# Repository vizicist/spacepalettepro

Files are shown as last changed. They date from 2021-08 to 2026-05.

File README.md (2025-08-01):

<h1>Space Palette Pro</h1>
<p>
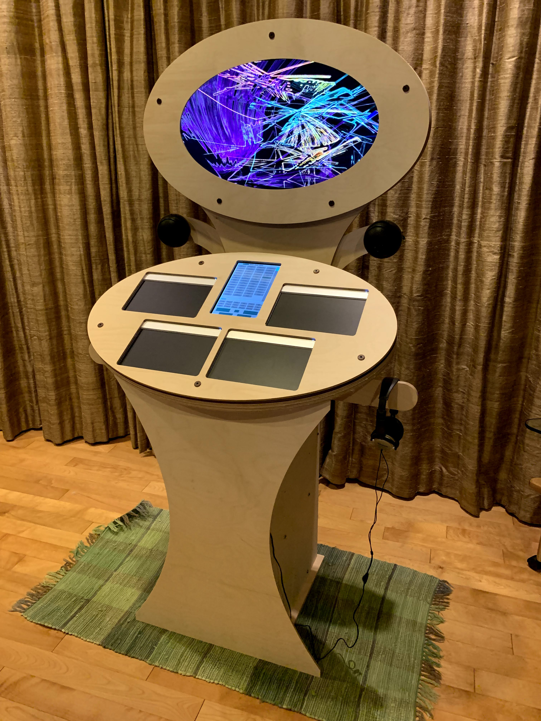
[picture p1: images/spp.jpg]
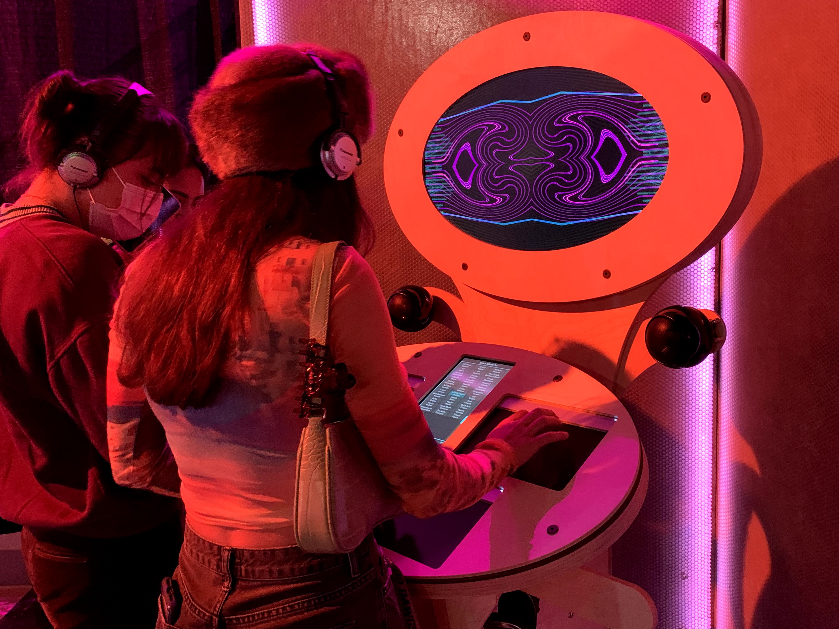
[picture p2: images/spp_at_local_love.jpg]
&nbsp;&nbsp;
<p>
NOTE: This repo is undergoing a massive rework for a more modular physical arrangement; the single monolithic
enclosure will be broken up into sections - one "core" section with all the electronics, and the other sections
will merely be support.  Besides being much easier to transport, it will also allow a desktop configuration.
The controller and monitor parts will be largely unchanged.
<p>
This repo contains open-source specs allowing you to completely reproduce the Space Palette Pro,
a visual music instrument on which you play music and graphics simultaneously by finger painting on
pressure sensitive pads.  Here are some <a href="https://photos.app.goo.gl/1x5BrCuc9yP6Z52XA">photos and videos</a> from a recent event where it was enjoyed.  Here is a <a href="https://youtu.be/HDtxEyCI_zc?t=362">improvised performance</a> using it.
<p>
Questions welcome, you can either submit an issue or email me@timthompson.com (aka <a href="https://nosuchtim.com">nosuchtim</a>)
<p>

<!--
<h2>Getting started with a single Morph as a visuals-only instrument</h2>
<p>
If you have Windows 10 and a Sensel Morph,
you can easily run the Palette software
as a visuals-only instrument with Resolume 7,
without building the complete Space Palette Pro.
It will even work with the demo version of Resolume Avenue or Arena.
Here are the instructions for
<a href="https://github.com/vizicist/palette/blob/main/doc/using_resolume.md">using a single Morph as a visuals-only instrument</a>.
-->

<h2>Building just the Space Palette Pro controller</h2>
<p>
Here are the instructions for <a href="doc/building_controller.md">building just the controller</a>,
which by itself would work well in many situations, for example doing performances.
In addition to 4 Morphs, you need the wood pieces, 2 USB hubs, the 10.1" touchscreen, and cables.

<!--
<h2>Building a complete and standalone Space Palette Pro</h2>
<p>
NOTE: If you plan on building a complete standalone Space Palette Pro, please send email to me@timthompson.com before starting,
since there have been major changes to the design of the base.
<p>
Here are the instructions for <a href="doc/building.md">building a complete and standalone Space Palette Pro</a> from scratch.
The cost of all the <a href="doc/parts.pdf">raw materials</a> for an uncompromised and complete instrument
including the computer is around $8K.
This is no-compromise single-item pricing of all materials - cost-reductions
and other adjustments are certainly possible.
For example, the speaker system is unnecessary
if you already have an amplifier and speakers.
Four sets of headphones and a headphone amp may not be needed either.
You might have access to a large CNC machine so you can avoid
paying someone else to CNC all the wood.
<p>
-->

<h1>Documentation</h1>
<a href="doc/README.md">Other documentation and important links can be found here.</a>
<p>
<p>
Any questions, email <a href="mailto:me@timthompson.com">me@timthompson.com</a>

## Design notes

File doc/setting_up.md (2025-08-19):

<h1>Setting up the Space Palette Pro</h1>
You should have these 5 pieces:
<br>1 - core box with all the electronics
<br>2 - oval controller with 4 Morphs
<br>3 - oval monitor
<br>4 - base boxes
<br>5 - plastic bin with misc. parts
<hr>
Here's the core box. Unscrew the thumbscrew, remove the protective panel, and screw the thumbscrew back into the core box.
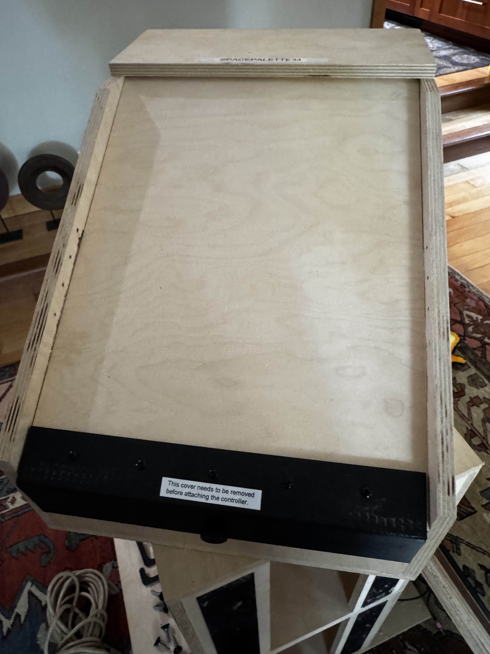
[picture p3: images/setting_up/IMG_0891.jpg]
<br>
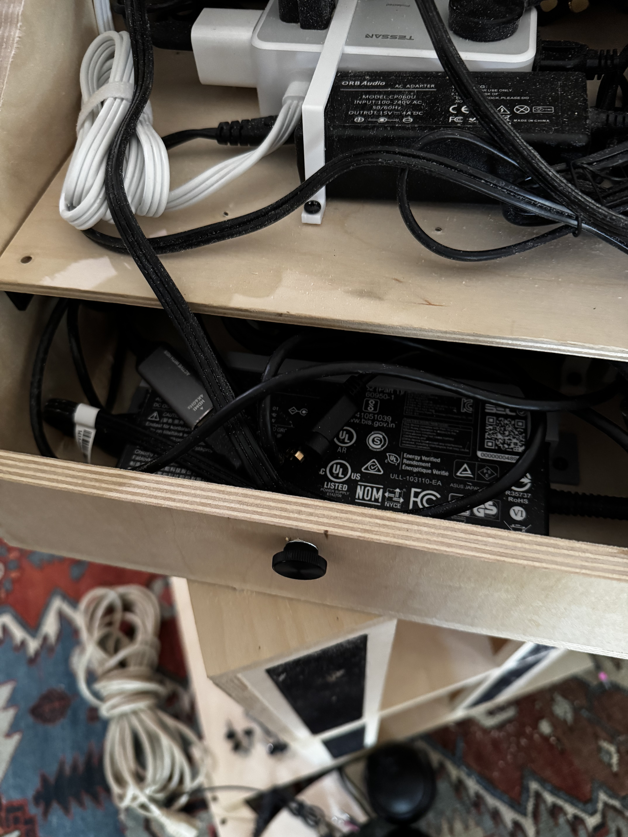
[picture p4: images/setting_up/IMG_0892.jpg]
&nbsp;
<hr>
The core box attaches to the base with 4 bolts (or thumbscrews) in the four corners of the box, which match up with four holes in the top of the base.
On the front side of the core box the holes are visible next to the power supply brick.
On the back side,
you'll need to unscrew the 2 thumbscrews on the back panel in order to fold the back panel down to get access to the two holes in the corners.
Getting these bolts in is the most finicky part of the setup, and small hands are an advantage.
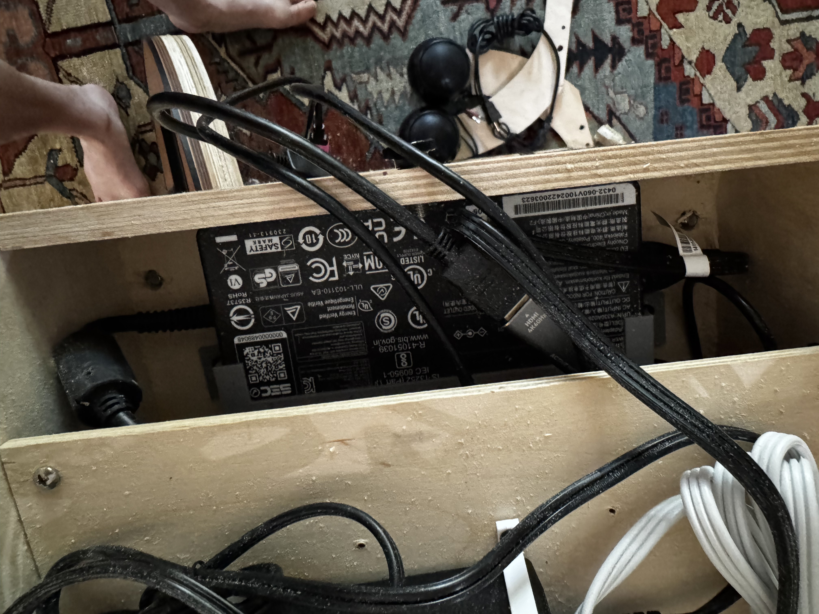
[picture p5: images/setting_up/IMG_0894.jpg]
<br>
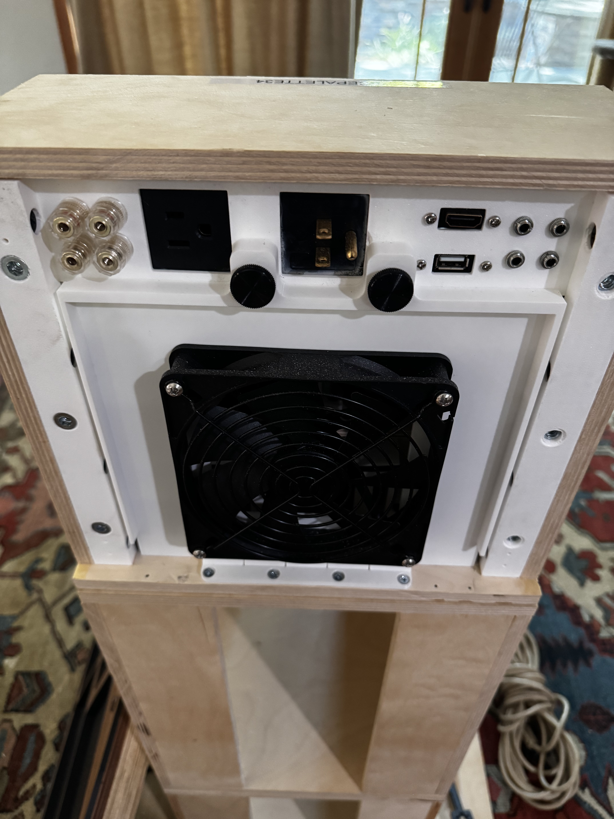
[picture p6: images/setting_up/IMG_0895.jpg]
&nbsp;
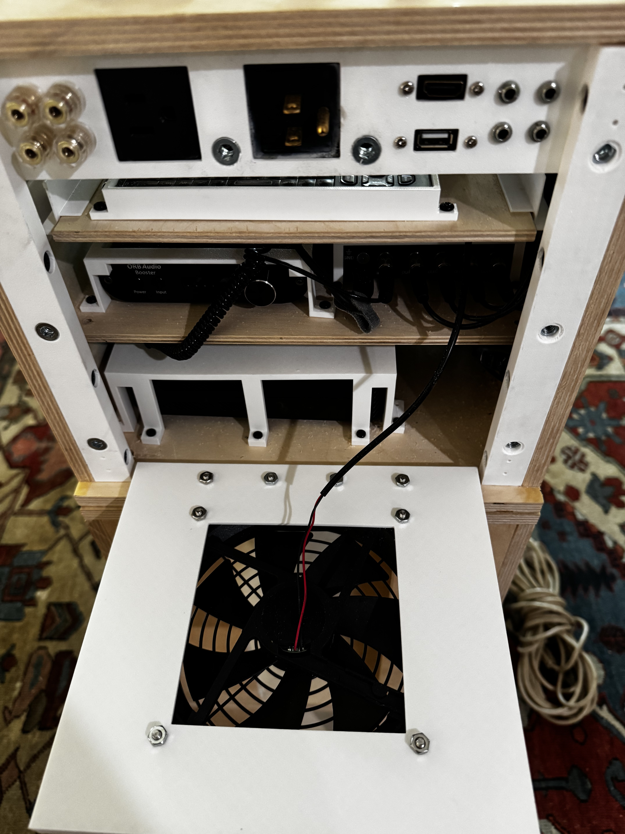
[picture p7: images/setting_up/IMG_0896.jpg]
&nbsp;
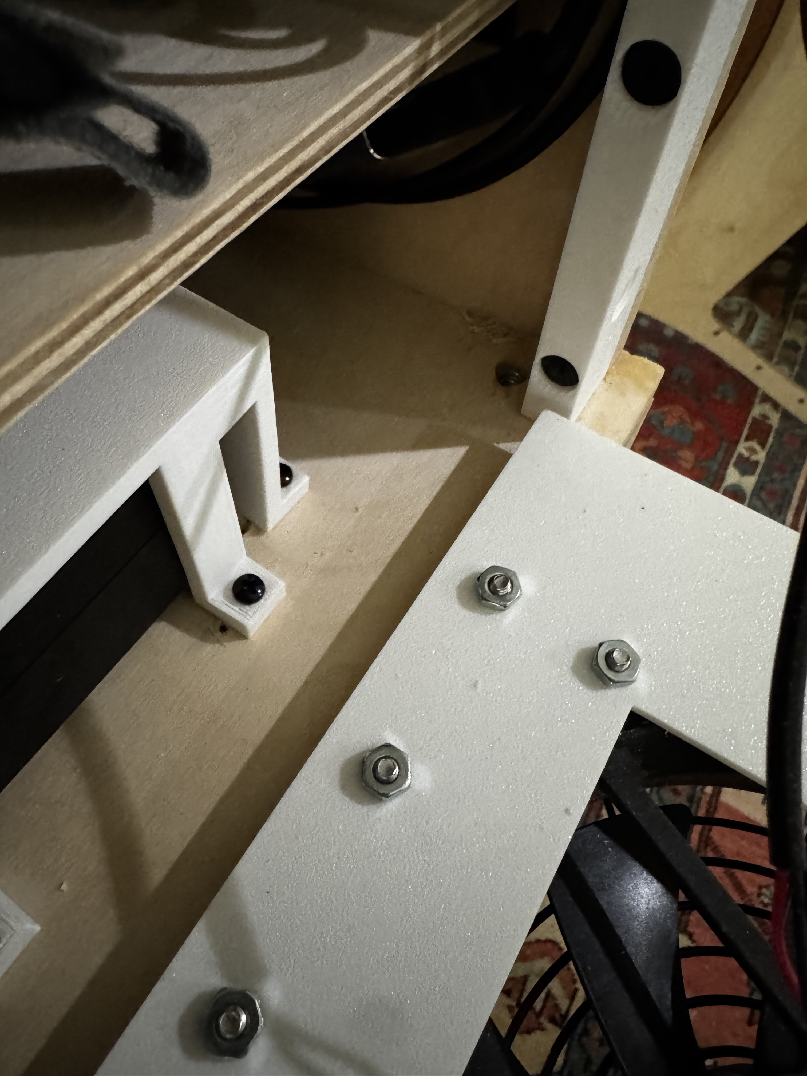
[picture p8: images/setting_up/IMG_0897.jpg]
&nbsp;
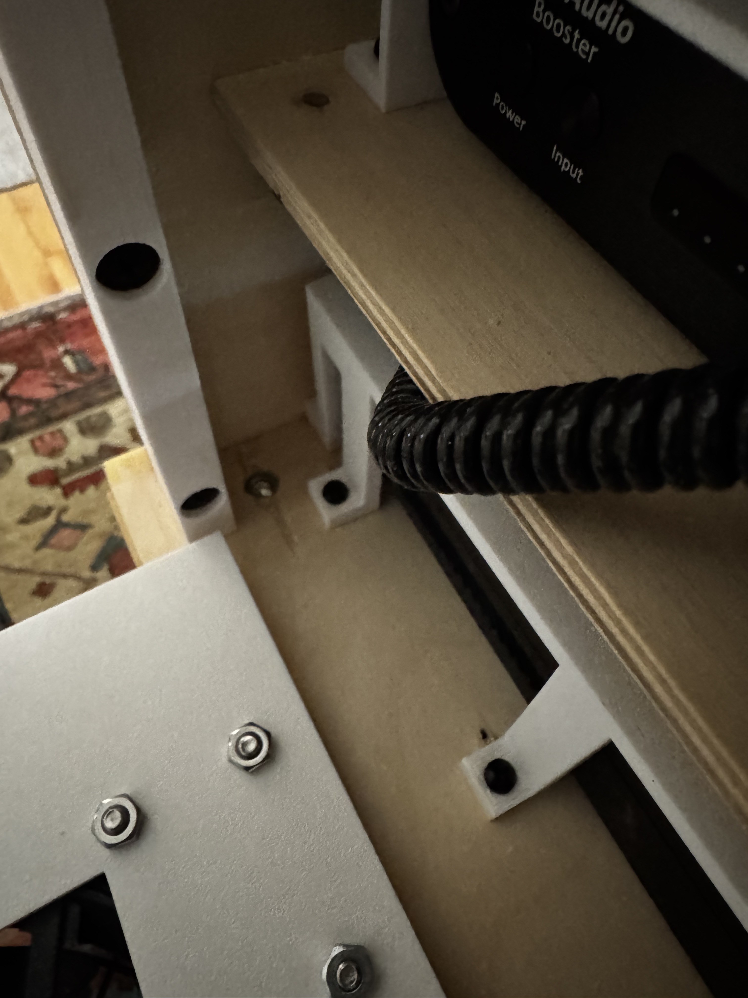
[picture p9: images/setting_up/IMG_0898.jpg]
&nbsp;
<hr>
Make sure you have these 2 cables (they are either in the plastic bin, or loose in the core box) before you attach the controller to the core box.  These are the 2 cables that will be connected to the monitor.
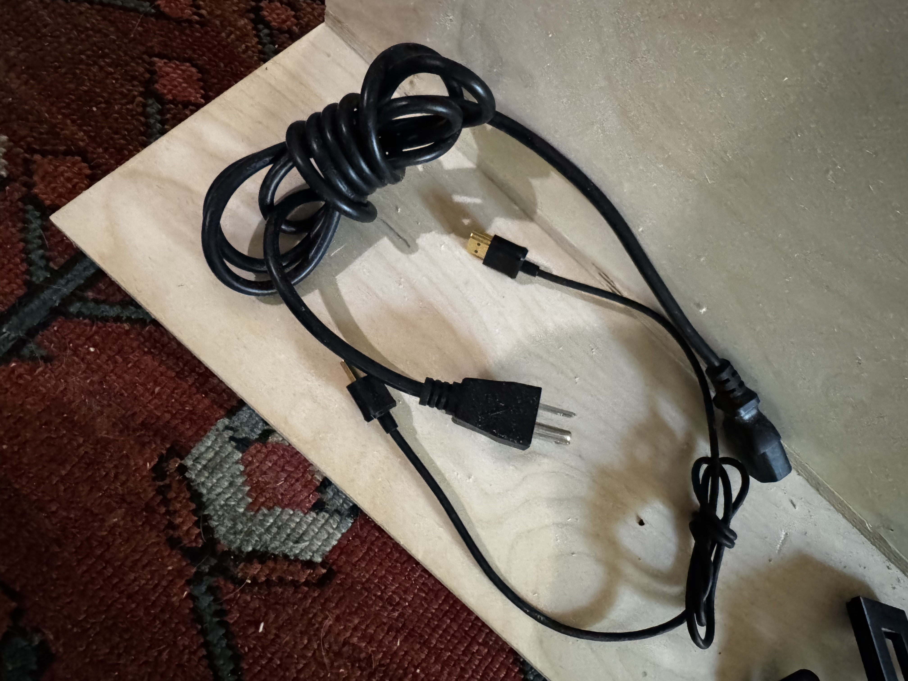
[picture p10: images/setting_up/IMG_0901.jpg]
<br>
<hr>
Identify the 3 cables (one HDMI, two USB C) in the core box that are going to connect to the oval controller.
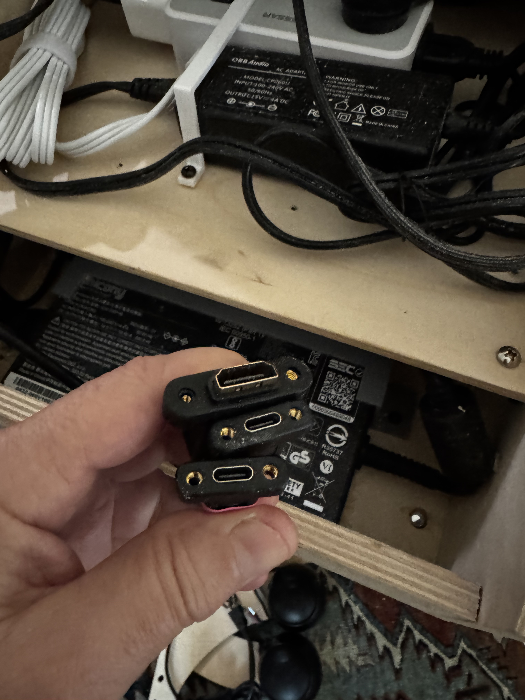
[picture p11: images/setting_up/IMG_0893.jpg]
<br>
<hr>
Position the oval controller close to the core so that you can connect the 3 cables from the controller to the core.  There are 2 USB C connections - one is colored pink, make sure that one is plugged into the corresponding pink connector.
<hr>
After connecting the 3 cables, place the oval controller on the core box, making sure that the 3 cables are tucked insude the core box, and use thumbscrews (2 on each side) to attach the oval controller to the core box.
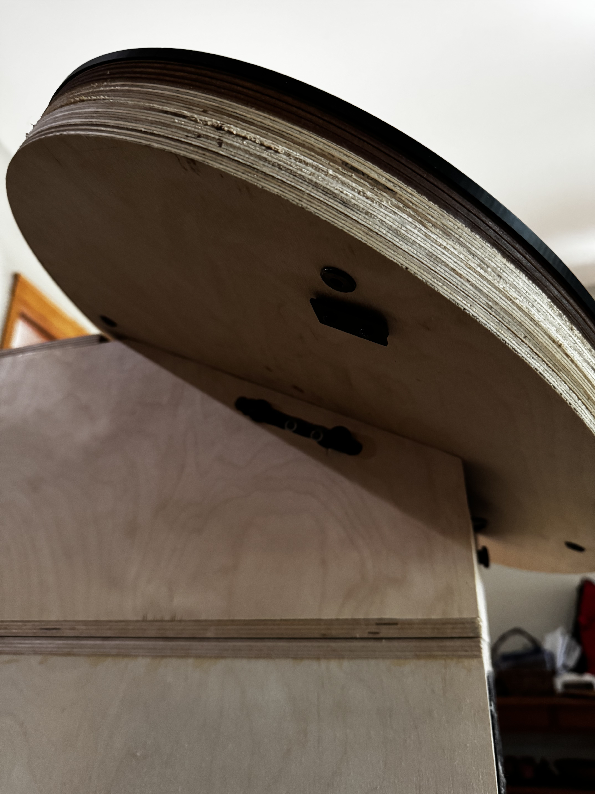
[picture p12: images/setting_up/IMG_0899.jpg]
<br>
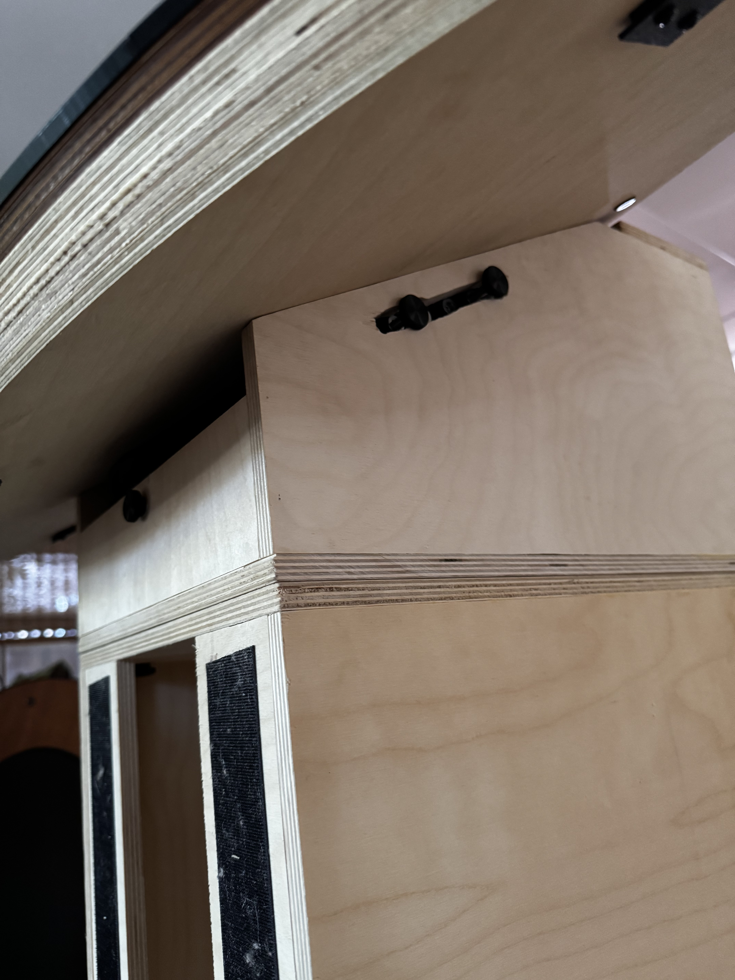
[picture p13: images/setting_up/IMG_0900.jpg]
&nbsp;
<hr>
Attach the monitor to the back of the core box with 6 thumbscrews.
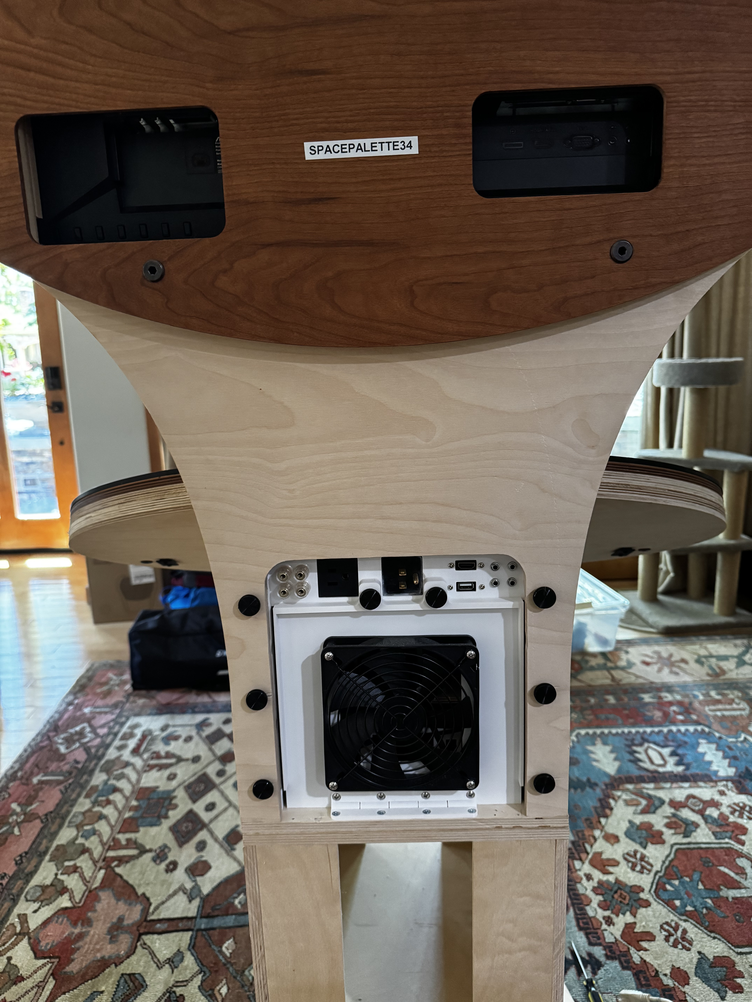
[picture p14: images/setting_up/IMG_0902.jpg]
<br>
<hr>
Connect the monitor to the back panel of the core box with 2 cables, one HDMI and one IEC/power.
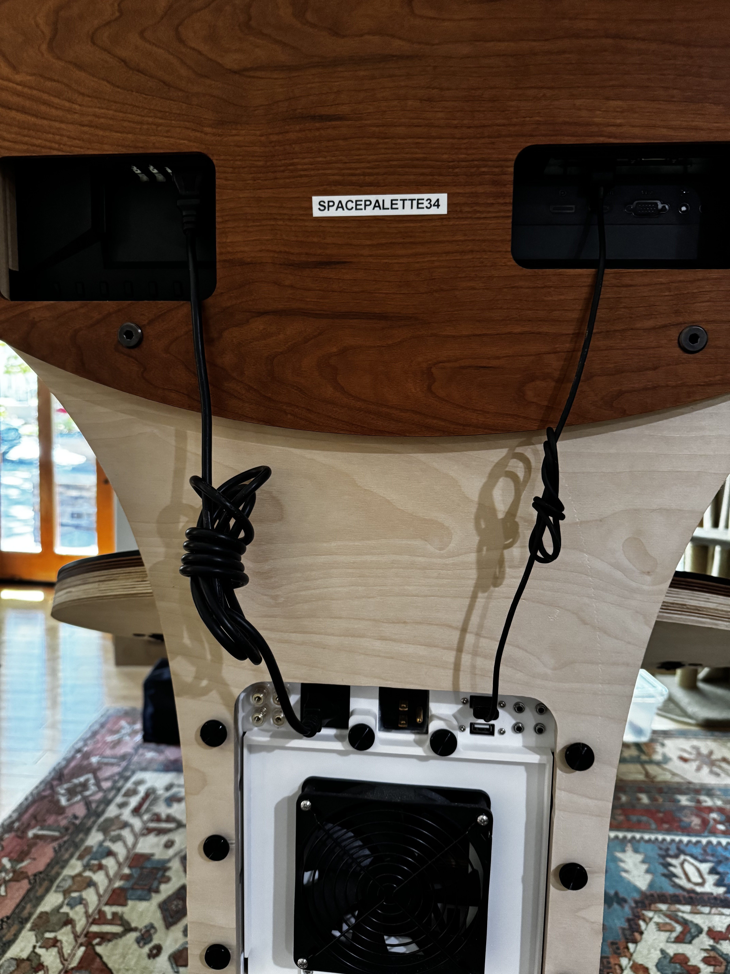
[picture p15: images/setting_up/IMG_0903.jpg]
<br>
<hr>
Slide the headphone hooks onto the matching plastic thing on the back side of the oval controller.
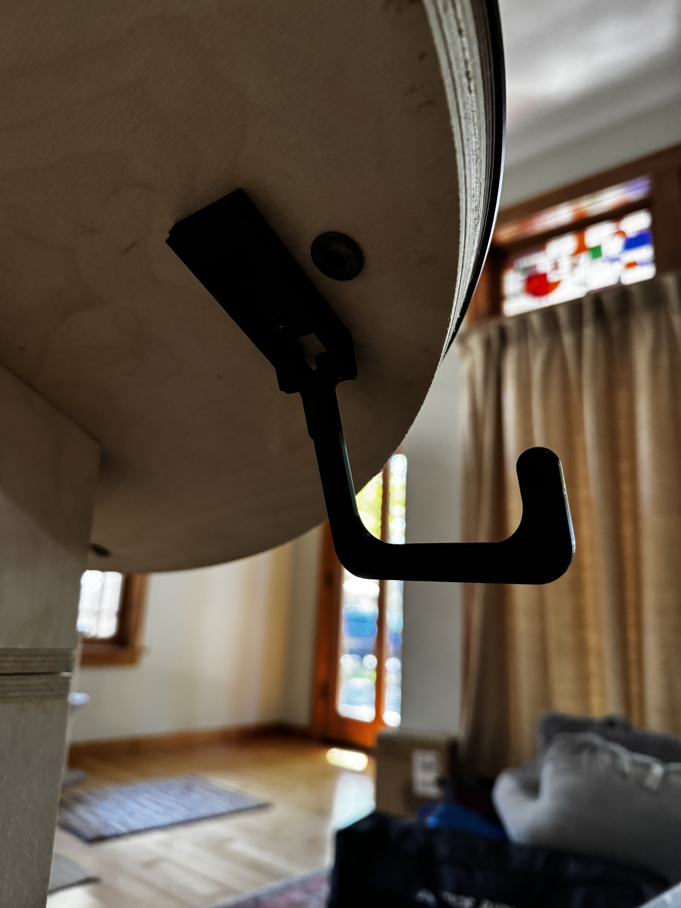
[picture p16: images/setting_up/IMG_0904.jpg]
<br>
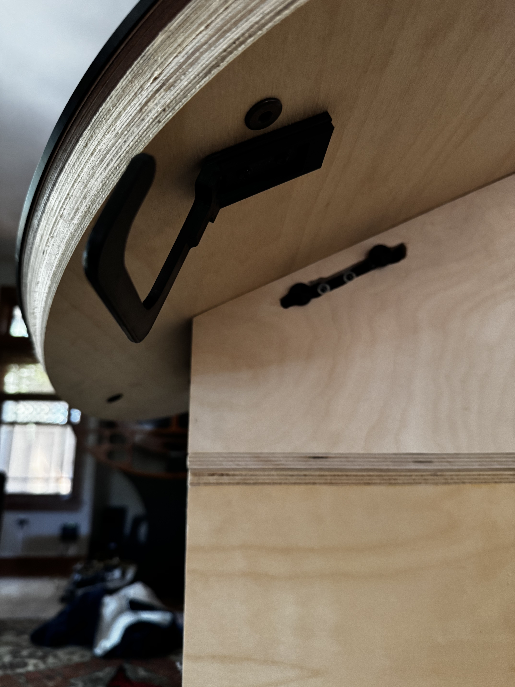
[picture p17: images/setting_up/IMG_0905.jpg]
&nbsp;
<hr>
Attach the speakers to the back, using (unscrewing/screwing) the thumbscrews that you've already used for the monitor.
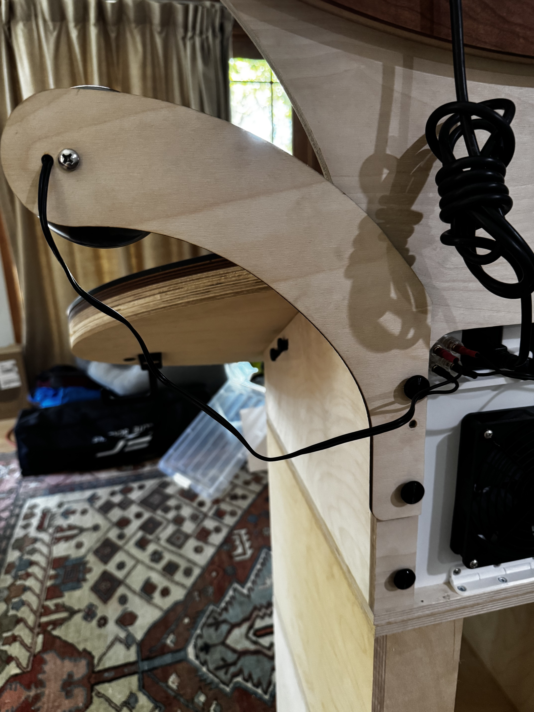
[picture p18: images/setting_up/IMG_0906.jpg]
<br>
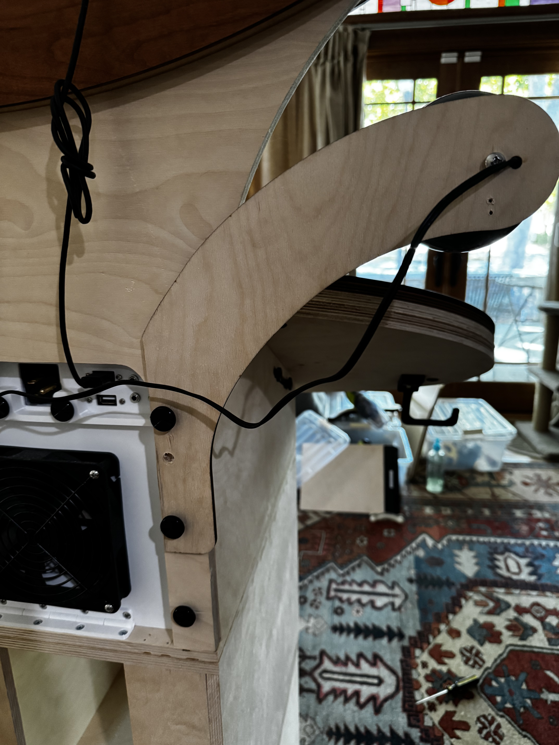
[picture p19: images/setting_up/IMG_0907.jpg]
&nbsp;
<hr>
Plug the banana plugs of the speakers into the jacks on the back panel.
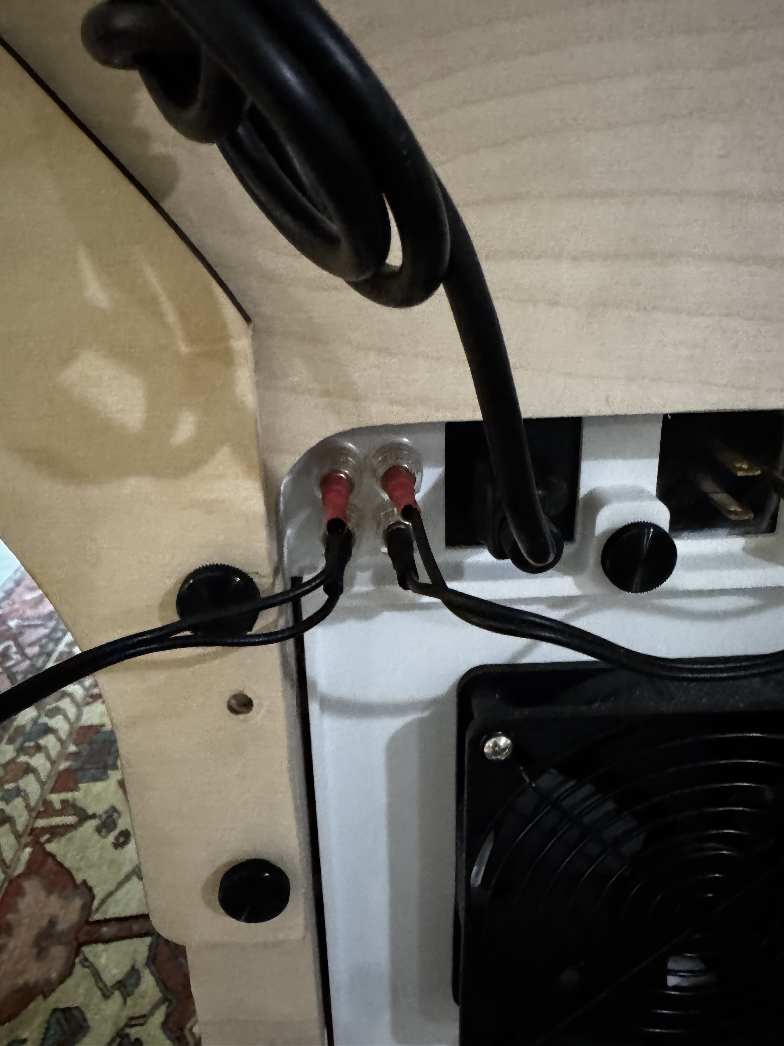
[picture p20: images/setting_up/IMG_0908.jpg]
<br>
<hr>
Plug the headphones into the jacks on the back panel.
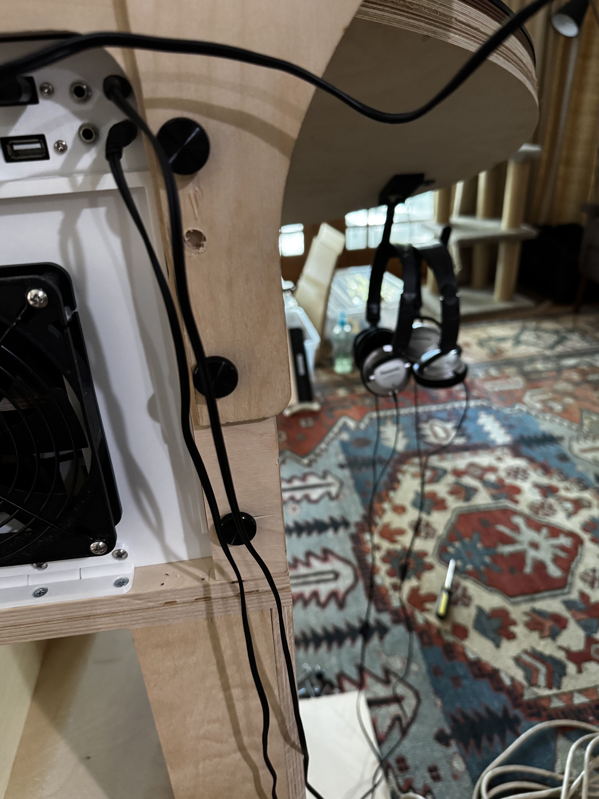
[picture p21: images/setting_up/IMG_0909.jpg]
<br>
<hr>
Plug the female end of a power cord into the male power connection on the back panel.  You may need to use a short extension cable.
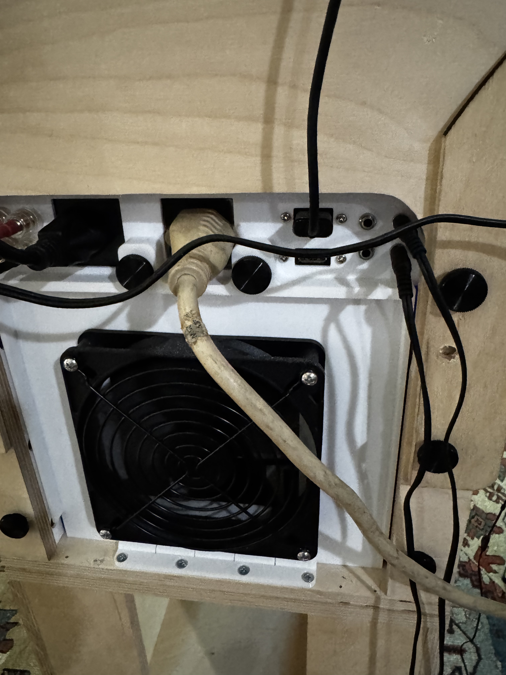
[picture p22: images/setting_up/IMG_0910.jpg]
<br>
<hr>
It should boot up in a few minutes after connecting the power.
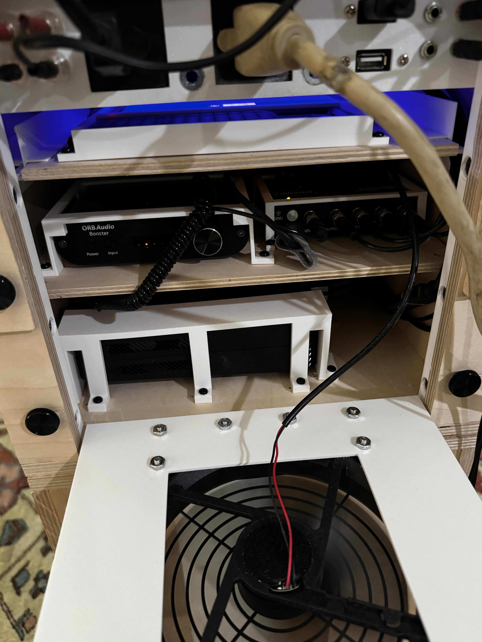
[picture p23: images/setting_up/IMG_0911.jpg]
<br>
<hr>
Normally, you shouldn't need to do anything else, but if there is a problem, you can check on things by sliding out the tiny keyboard and monitor after opening the back panel.  The keyboard has a trackpad on the right side.  You may need to press the blue FN key on the lower left of the keyboard, to wake up the keyboard.  The trackpad should move the mouse, but the cursor may be on the other screens, so you'll have to move it around in order to see it.
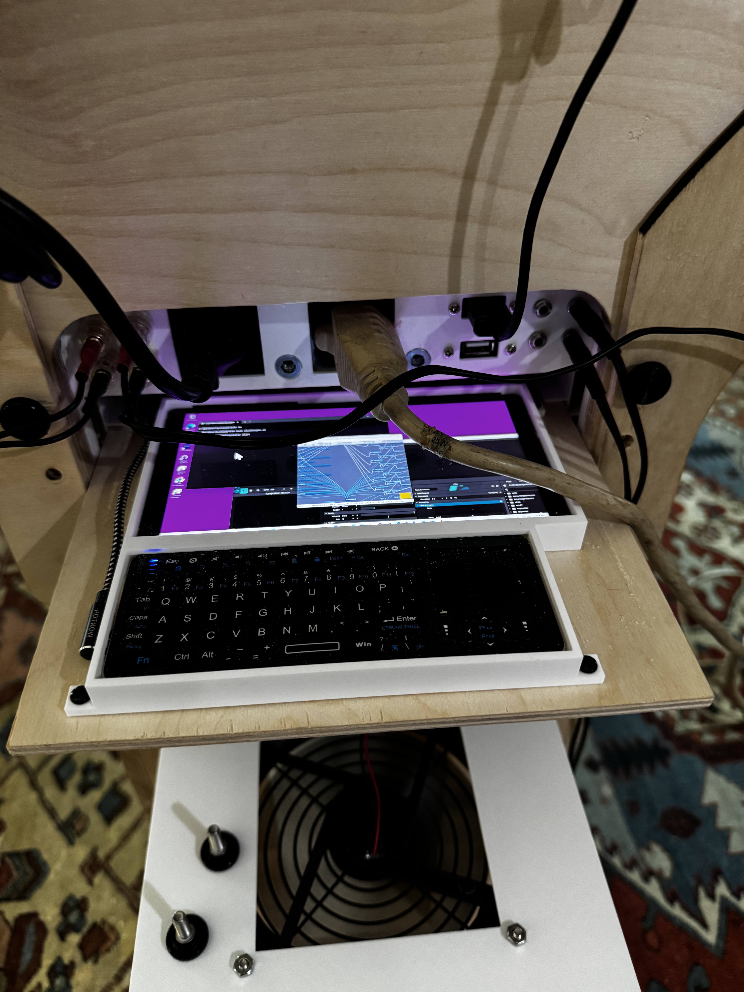
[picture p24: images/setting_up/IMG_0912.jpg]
<br>
<hr>
This is what the back looks like with everything connected.
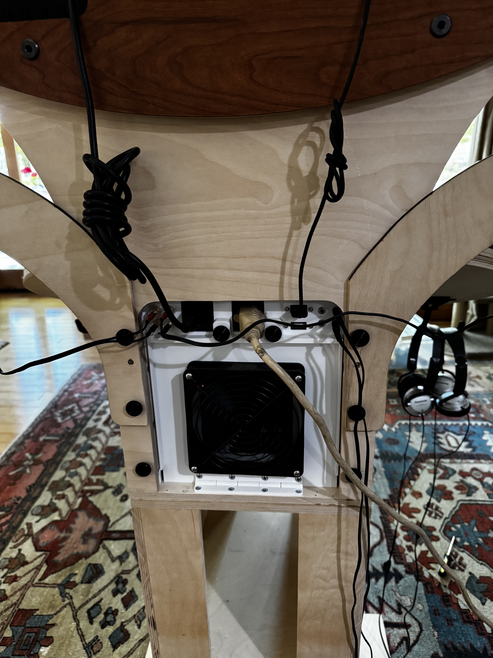
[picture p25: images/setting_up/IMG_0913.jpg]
<br>
<hr>
Put the hourglass panel on the front of the base, it attaches with velcro.
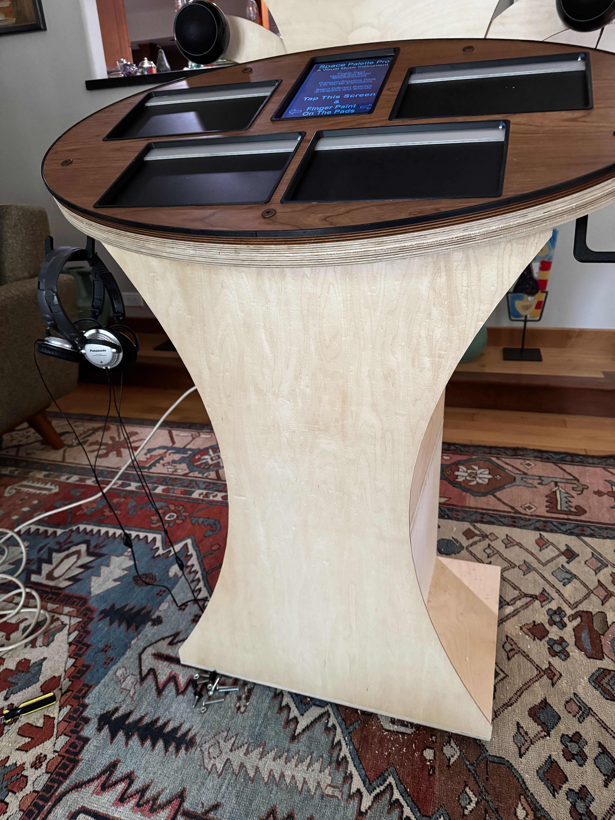
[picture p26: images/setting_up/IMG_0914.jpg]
<br>
<hr>
If you need to adjust the volume of the speakers, that is done with a single big knob on the speaker amp, accessible inside the back panel.  The headphones have volume controls on their cables for individual control.
<hr>
<h2>You now have a Space Palette Pro!</h2>

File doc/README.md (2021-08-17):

<h1>Space Palette Pro - documentation & other links</h1>
<p>
<li>
<a href="parts.pdf">Complete parts list with links and prices</a><br>
This is for the exact parts, down to the bolts,
needed to duplicate an uncompromised and complete instrument.
If you're viewing this file on GitHub,
the URL links for the parts won't be active
unless you download this .pdf and view it directly.
This parts list originates in a <a href="parts.ods">spreadsheet format</a>.
<p>
<li>
<a href="building.md">Full instructions for building it.</a>
<p>
<li>
<a href="../dxf/list.md">List of wood pieces with CNC data and pictures.</a>
<p>
<li>
<a href="computer_quote.pdf">Specs for the computer.</a>
<p>
<li>
<a href="https://github.com/vizicist/palette">Source code for the Palette software</a>
<p>
</ul>

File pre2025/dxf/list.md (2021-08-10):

<h1>DXF data for building a Space Palette Pro</h1>
<p>
Note carefully the quantity of each and the varying thicknesses.
<p>
<h1>Controller</h1>
<p>
<!-- NOTE: there must be a blank line before the table -->

| Quantity | Thickness | Filename | Image |
| --- | --- | --- | --- |
| 1 | 1/4" | <a href="SPP_Layer1_face.dxf">SPP_Layer1_face.dxf</a> |  |
| 1 | 1/8" | <a href="SPP_Layer2.dxf">SPP_Layer2.dxf</a> |  |
| 1 | 1/8" | <a href="SPP_Layer3.dxf">SPP_Layer3.dxf</a> |  |
| 1 | 1/8" | <a href="SPP_Layer4.dxf">SPP_Layer4.dxf</a> |  |
| 1 | 1/2" | <a href="SPP_Layer5.dxf">SPP_Layer5.dxf</a> |  |
| 1 | 1/2" | <a href="SPP_Layer6.dxf">SPP_Layer6.dxf</a> |  |
| 1 | 1/4" | <a href="SPP_Layer7_back.dxf">SPP_Layer7_back.dxf</a> |  |
<p>
<h1>Monitor</h1>
<p>
<!-- NOTE: there must be a blank line before the table -->

| Quantity | Thickness | Filename | Image |
| --- | --- | --- | --- |
| 1 | 1/4" | <a href="SPP_MonLayer1_face.dxf">SPP_MonLayer1_face.dxf</a> |  |
| 2 | 1/2" | <a href="SPP_MonLayer2_3_bottom.dxf">SPP_MonLayer2_3_bottom.dxf</a> |  |
| 4 | 1/2" | <a href="SPP_MonLayer2_3_leftright.dxf">SPP_MonLayer2_3_leftright.dxf</a> |  |
| 2 | 1/2" | <a href="SPP_MonLayer2_3_top.dxf">SPP_MonLayer2_3_top.dxf</a> |  |
| 1 | 1/2" | <a href="SPP_MonLayer4.dxf">SPP_MonLayer4.dxf</a> |  |
| 1 | 1/2" | <a href="SPP_MonLayer5.dxf">SPP_MonLayer5.dxf</a> |  |
| 1 | 1/4" | <a href="SPP_MonLayer6_back.dxf">SPP_MonLayer6_back.dxf</a> |  |
<p>
<h1>Base</h1>
<p>
<!-- NOTE: there must be a blank line before the table -->

| Quantity | Thickness | Filename | Image |
| --- | --- | --- | --- |
| 1 | 1/2" | <a href="SPP_BaseBack.dxf">SPP_BaseBack.dxf</a> |  |
| 1 | 1/2" | <a href="SPP_BaseBackBottom.dxf">SPP_BaseBackBottom.dxf</a> |  |
| 1 | 1/2" | <a href="SPP_BaseBottom.dxf">SPP_BaseBottom.dxf</a> |  |
| 1 | 1/4" | <a href="SPP_BaseFront.dxf">SPP_BaseFront.dxf</a> |  |
| 1 | 1/2" | <a href="SPP_BaseHeadphones.dxf">SPP_BaseHeadphones.dxf</a> |  |
| 1 | 1/2" | <a href="SPP_BaseKeyboard.dxf">SPP_BaseKeyboard.dxf</a> |  |
| 1 | 1/4" | <a href="SPP_BaseMidShelf.dxf">SPP_MidShelf.dxf</a> |  |
| 1 | 1/4" | <a href="SPP_BaseMonKeyShelf.dxf">SPP_MonKeyShelf.dxf</a> |  |
| 2 | 1/2" | <a href="SPP_BaseSide.dxf">SPP_BaseSide.dxf</a> |  |
| 2 | 1/4" | <a href="SPP_BaseSpeaker.dxf">SPP_BaseSpeaker.dxf</a> |  |
| 1 | 1/4" | <a href="SPP_BaseTopShelf.dxf">SPP_BaseTopShelf.dxf</a> |  |
<p>

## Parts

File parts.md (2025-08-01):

Space Palette Pro parts list

3d prints

	monkey holder
	monkey cable holder
	2x amp support
	headphone amp support
	4x angle4shelf (maybe rework to wide 2x)
	power brick support
	2x nuc support
	port panel
	2x ladder
	2x sliding side for monkey (make stronger)
	2x hinge for fan door
	2x speaker cable cover
	2x headphone hangers (A&B parts)

components

	Peakdo monitor
	Rii keyboard/mouse
	orb amp & power brick
	headphone amp
	power strip
	nuc 970 & power brick
	2x power cube
	usb fan

cables

	2x displayport to hdmi female
	mini hdmi to hdmi (for pico monitor)
	3-prong short male ac to 3-prong (to NUC power brick)
	3-prong short male ac to 3-prong female ac (to panel)
	usb Y-cable (Peakdo monitor or Rii keyboard package) usb c male to USB A female and male
	hdmi M/M short cable (from portpanel to big monitor)
	usb a female mount to usb a male
	hdmi female mount to hdmi male
	usb c (right angle) to usba (short)
	4x 1/8" stereo panel mount to male 1/8"
	1/8" stereo Y cable male to male/male (coiled)
	4x speaker cable (2 pairs black/red panel mounts to banana plugs)
	ac iec 3-prong short to big mon

wood box (one, need 2)

	2x   18 1/2" x 14"
	2x   18 1/2" x 12"
	4x   14" x 3"

wood bottom

	24" x 18 3/4"

wood core

	1/2" baltic birch (sides):
		18 1/2" x 12"
		12" x 5"
		2x   18 x 10" with diagonal 6 1/2" at top, 4 1/4" at side
		11 1/16" x 3"

	1/4" birch (shelves):
		14 x 11"
		8 x 8 7/8"

bolts and screws
    4 - 8-32 bolt - 1 3/8"  for attaching fan to panel
    4 - 8-32 bolt - 3/8" for attaching fan panel to hinge
    8 - 8-32 nuts
    4 - #6 x 1/2" flat head zinc philips for attaching hinge to base

    8 - threaded inserts 1/4-20 x 10mm 

    lots - #6 x 3/8" black wood screws for attaching to 1/8" shelves

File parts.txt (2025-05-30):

Space Palette Pro parts list

3d prints

	monkey holder
	monkeycable holder
	2x amp support
	headphone amp support
	4 × angleyshelf maybe legiel!
	powerr brick support
	2x nuc support
	port panel
	2x ladder
	2x sliding side for monkey (ms#kencer)
	2x hinge for fan poor
	-zis.ee#pkernear-keerkear& b)

components

	pico monitor
	pico keyboard
	orb amp & power brick
	headphone amp
	power strip
	nuc 970 & power brick
	2x power cube
	usb fan

cables

	2x displayport to hdmi female
	mini hdmi to hdmi (for pico monitor)
	3-prong short male ac to iec 3-prong (to NUC power brick)
	bp short male ac to 3p female ac (to panel)
	usb x-cable (pico mon orikey package) usb c to
	hdmi m-mi short to bigmon usba female immale
	usb a female mount to usb a male
	hdmi female mount to hdmi male
	usb c (right angle) to usba (short)
	4x 1/8" stereo panel mount to male 1/8"
	4x speaker cable
	ac iec 3-prong short to big mon

wood box (one, need 2)

	2x   18 1/2" x 14"
	2x   18 1/2" x 12"
	4x   14" x 3"

wood bottom

	24" x 18 3/4"

wood core

	8 1/4" x 8 15/16"  (with 5 1/4" hole)
	18 1/2" x 12"
	12" x 5"
	2x   18 x 10" (with diagonal 6 1/2" at top, 4 1/4" at side
	11 1/16" x 3"
	2x 10" x 1"

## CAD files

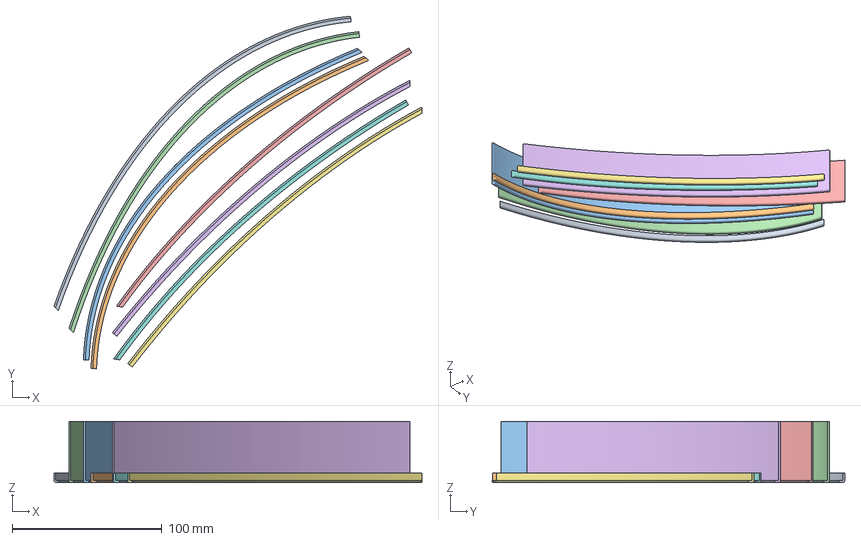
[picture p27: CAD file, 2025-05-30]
cad/SPP_Edge_AB_All.3mf
246.1 x 235.8 x 40.8 mm
SPP_Edge_B_0.25.stl
SPP_Edge_B_0.25_flipped.stl
SPP_Edge_B_1.5_flipped.stl
SPP_Edge_B_1.5.stl
SPP_Edge_A_1.5_flipped.stl
SPP_Edge_A_1.5.stl
SPP_Edge_A_0.25.stl
SPP_Edge_A_0.25_flipped.stl

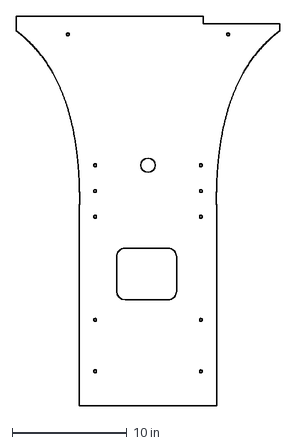
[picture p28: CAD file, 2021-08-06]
doc/cnc/PalPro_BaseBack.dxf
23.0 x 34.0 in

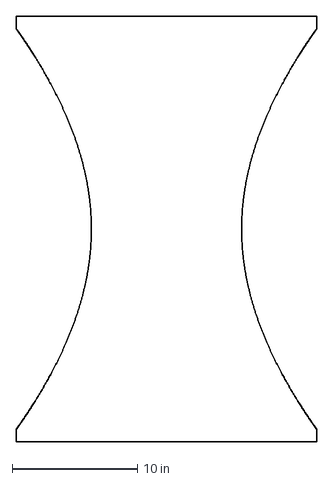
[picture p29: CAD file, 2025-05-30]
dxf/2025/basefront_noholes.dxf
24.0 x 34.0 in

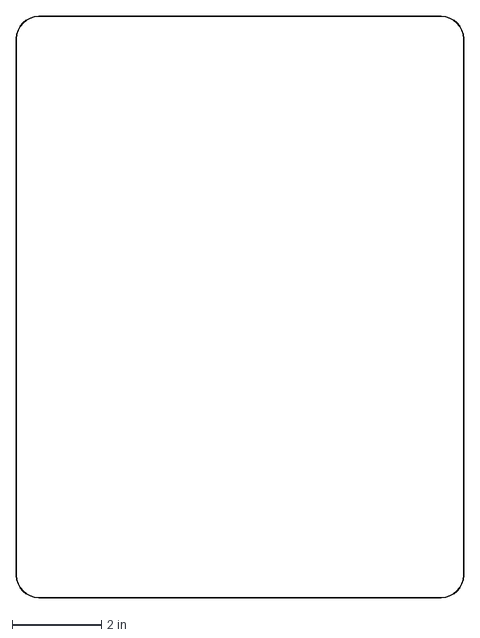
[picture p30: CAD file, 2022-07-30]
dxf/SPP_baseboxes_medium_outerinsert.dxf
10.0 x 13.0 in

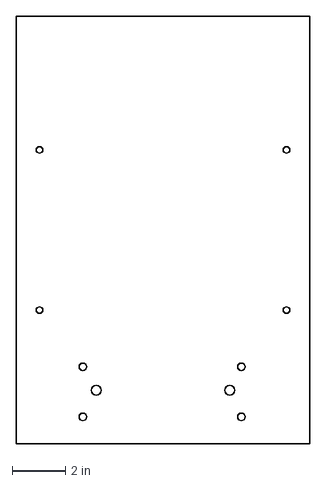
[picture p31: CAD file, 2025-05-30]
pre2025/dxf/SPP_BaseTopShelf.dxf
11.0 x 16.0 in

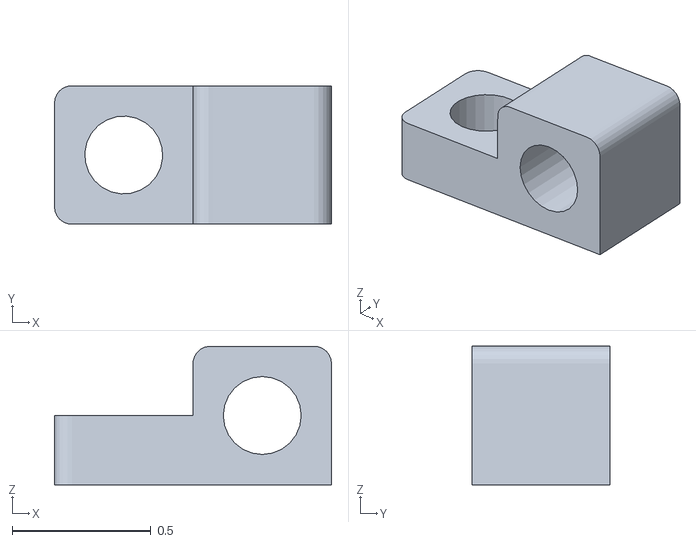
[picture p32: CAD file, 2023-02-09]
pre2025/stl/two_hole_bracket_sketchup.stl
1.00 x 0.5 x 0.5

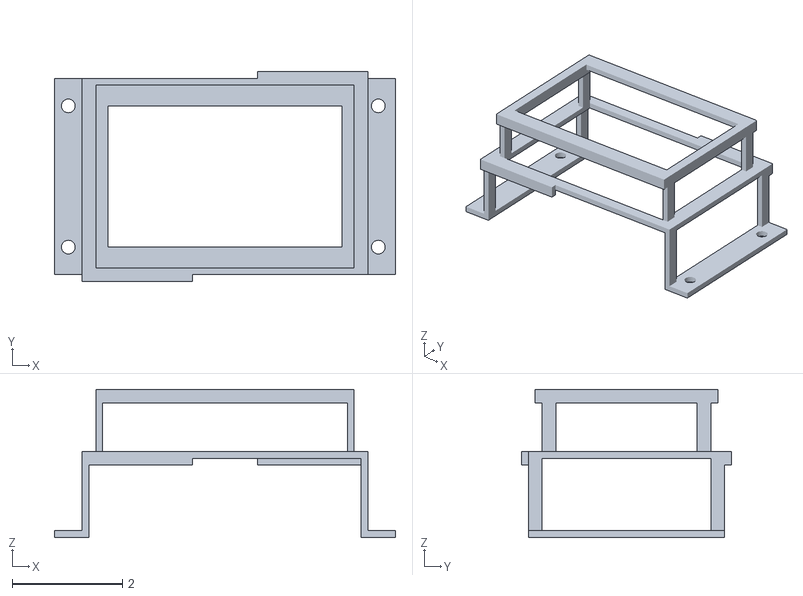
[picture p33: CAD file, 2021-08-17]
stl/amp_bracket.stl
6.19 x 3.81 x 2.69

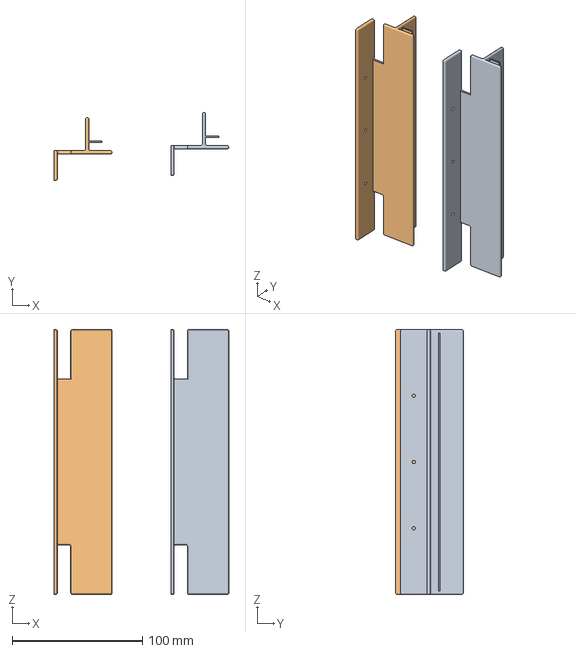
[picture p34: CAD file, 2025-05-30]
cad/SPP_sidesupport.3mf
133.9 x 52.1 x 203.2 mm
SPP_sidesupport.stl x 2

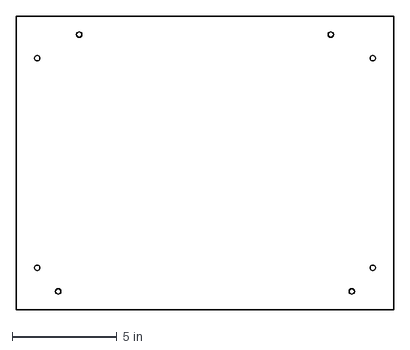
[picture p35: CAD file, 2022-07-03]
dxf/SPP_basebox_side.dxf
18.0 x 14.0 in

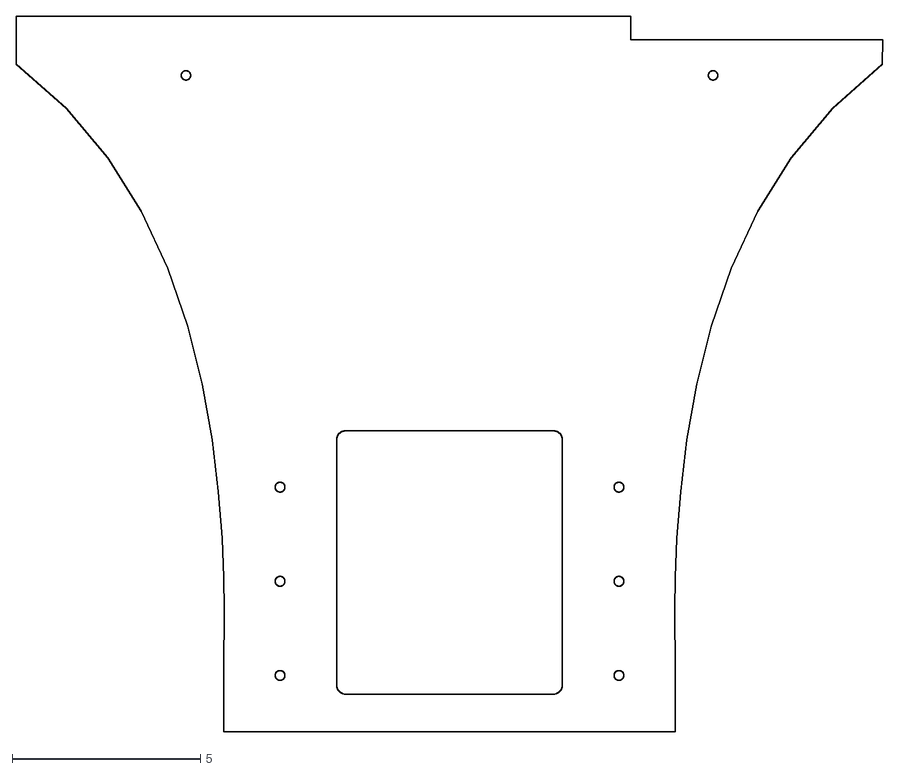
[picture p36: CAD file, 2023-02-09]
pre2025/dxf/SPP_BaseBack_skp.dxf
23.0 x 19.0

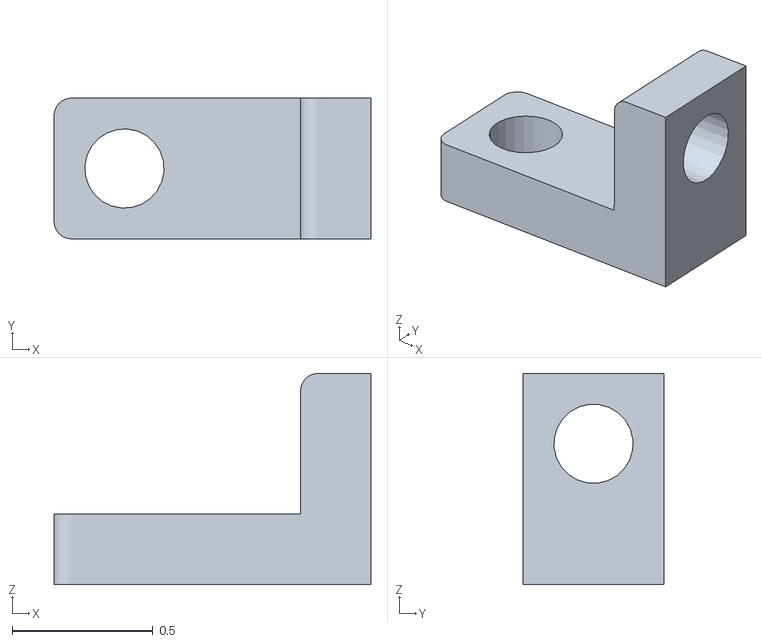
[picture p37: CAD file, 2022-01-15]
pre2025/stl/two_hole_front_bracket.stl
1.12 x 0.5 x 0.75

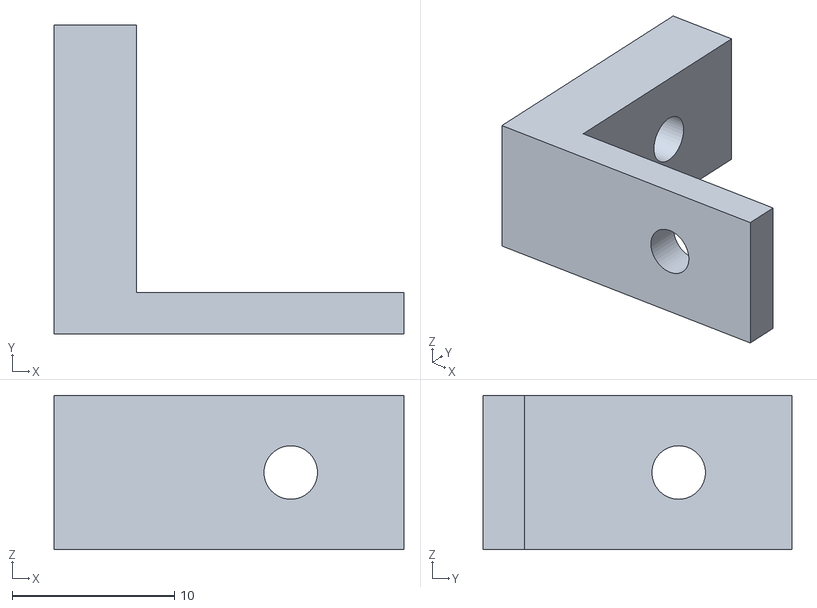
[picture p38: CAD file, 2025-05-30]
cad/SPP_angle4front.stl
21.6 x 19.0 x 9.53

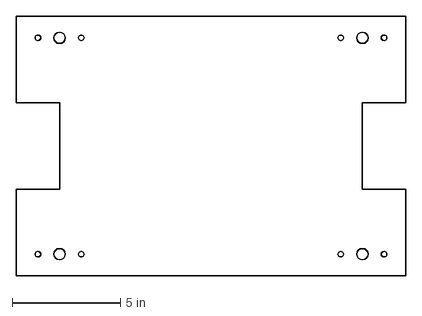
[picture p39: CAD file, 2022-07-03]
dxf/SPP_basebox_bottom.dxf
18.0 x 12.0 in

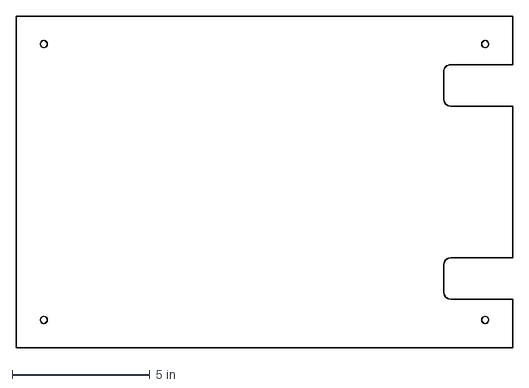
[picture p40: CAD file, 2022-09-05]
pre2025/dxf/SPP_baseboxes_top_bottom.dxf
18.0 x 12.0 in

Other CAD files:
pre2025/stl/two_hole_bracket.stl
cad/SPP_hinge.3mf
dxf/SPP_basebox_frontback.dxf
pre2025/dxf/SPP_baseboxes_medium_back_outer.dxf
cad/SPP_Edge_A_0.25.stl
cad/SPP_Edge_A_0.25_0.1.3mf
cad/SPP_Edge_A_0.25_flipped.3mf
cad/SPP_Edge_A_0.25_flipped.stl
cad/SPP_Edge_A_1.5.3mf
cad/SPP_Edge_A_1.5.stl
cad/SPP_Edge_A_1.5_flipped.3mf
cad/SPP_Edge_A_1.5_flipped.stl
cad/SPP_Edge_A_all.3mf
cad/SPP_Edge_All.3mf
cad/SPP_Edge_All_Old.3mf
cad/SPP_Edge_B_0.25.stl
cad/SPP_Edge_B_0.25_flipped.stl
cad/SPP_Edge_B_1.5.stl
cad/SPP_Edge_B_1.5_both.3mf
cad/SPP_Edge_B_1.5_flipped.stl
cad/SPP_Edge_B_all.3mf
cad/SPP_InnerEdge_A_0.25.stl
cad/SPP_InnerEdge_All.3mf
cad/SPP_InnerEdge_B_0.25.stl
cad/SPP_InnerSupport.3mf
cad/SPP_InnerSupport.stl
cad/SPP_Layer1_face.dxf
cad/SPP_Layer2.dxf
cad/SPP_Layer3.dxf
cad/SPP_Layer4.dxf
cad/SPP_Layer5.dxf
cad/SPP_Layer6.dxf
cad/SPP_Layer7_Backb.dxf
cad/SPP_MonLayer1_face.dxf
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

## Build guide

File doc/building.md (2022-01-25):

<h1>Building the Space Palette Pro</h1>
These are the steps to building a complete system.
<p>
<ul>
<li>Build the software
<li>Try it out
<li>Decide whether to go further
<li>Buy the parts
<li>Cut the wood
<li>Build the controller
<li>Build the monitor
<li>Build the base
<li>Attach those 3 pieces
<li>Connect all the wires
</ul>
Each of those steps is described below.
<p>

<hr>
<h1>Build the software</h1>
Here are the instructions for <a href="building_software.md">installing and setting up the software</a>.

<hr>
<h1>Buy the parts</h1>
The <a href="parts.ods"><code>parts.ods</code></a> file is a
spreadsheet listing all of the non-wood parts needed.
<a href="parts.pdf"><code>parts.pdf</code></a> is a large printable version, and
if you download this PDF and display it in your browser, the links will
be enabled and point to the places (mostly Amazon) where you can buy each piece.

<hr>
<h1>Cut the wood</h1>
A list of the wood pieces with pictures of each can be found in <a href="../dxf/list.md"><code>dxf/list.md</code></a>.
The <a href="../dxf/list.txt"><code>dxf/list.txt</code></a> file is a more concise list
that shows for each piece the quantity, thickness, and DXF filename.
Most of these pieces should be baltic birch, but some of them can be another material, particularly
the inner layers of the monitor and controller.  For example, MDF is an alternative to baltic birch at <a href="https://sendcutsend.com">sendcutsend.com</a>, a mail-order CNC service.
In the <a href="parts.pdf">parts list</a>,
the prices are taken from <a href="https://sendcutsend.com">sendcutsend.com</a>,
using MDF for the inner layers.
For the top layer of the controller (SPP_Layer1_face.dxf) and the top layer
of the monitor (SPP_MonLayer1_face.dxf), you might consider using
<a href="https://www.buyappleply.com/">ApplePly</a> for a nicer wood appearance.

<hr>
<h1>Build the controller</h1>
Here are the <a href="building_controller.md">instructions for building the controller</a>.

<hr>
<h1>Build the monitor</h1>
Here are the <a href="building_monitor.md">instructions for building the monitor</a>.

<hr>
<h1>Build the base</h1>
Here are the <a href="building_base.md">instructions for building the base</a>.

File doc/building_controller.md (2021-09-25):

<h1>Building the Controller of the Space Palette Pro</h1>
Put the face layer (the top and visible part of the controller) face down, with the bronze 1.57" connector bolts inserted.
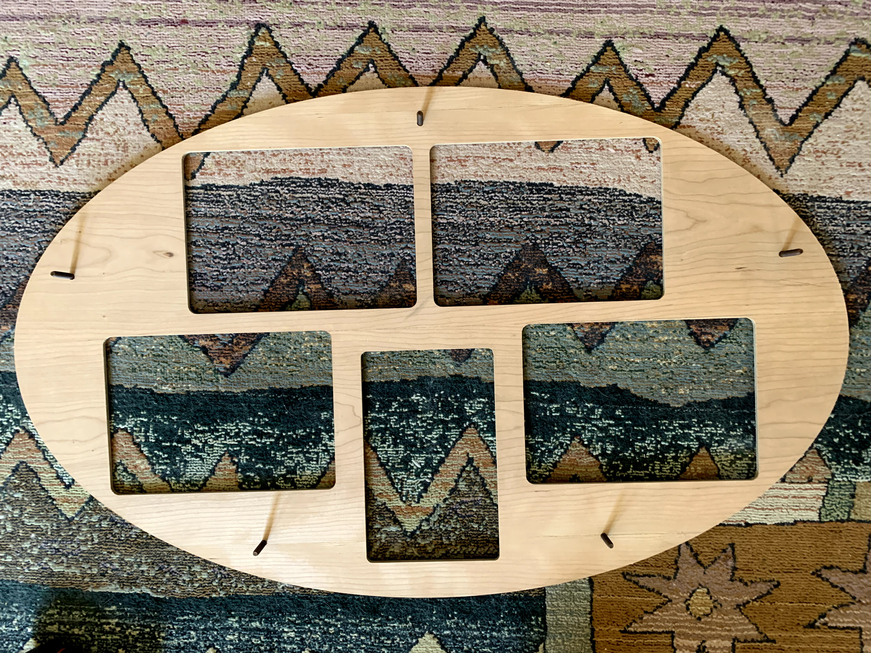
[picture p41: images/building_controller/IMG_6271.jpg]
<br>
<p>
<hr><hr>
Put Layer2 on.  Make sure it's oriented as shown.
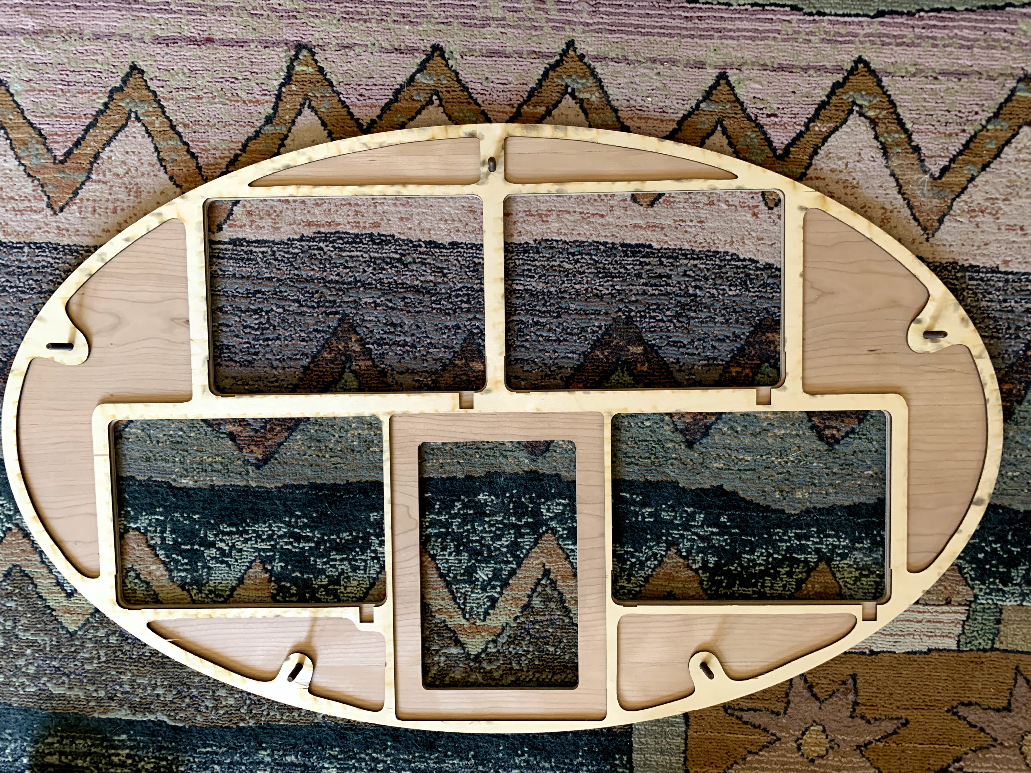
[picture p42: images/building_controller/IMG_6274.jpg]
<br>
<p>
Here's a closeup of the alignment in one of the corners.
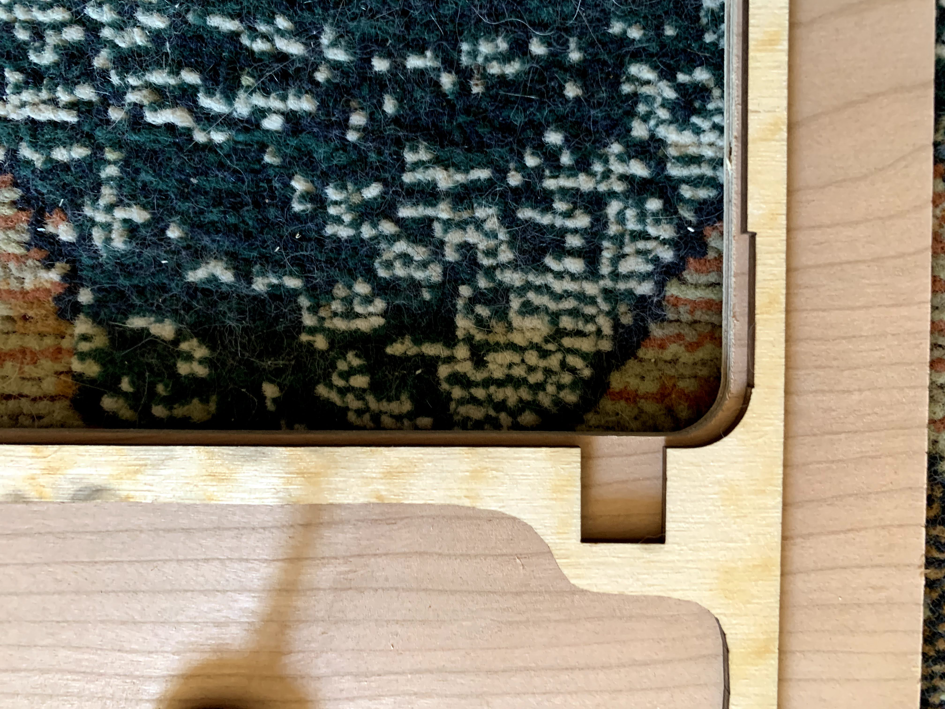
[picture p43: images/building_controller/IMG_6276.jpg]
<br>
<p>
<hr><hr>
Put Layer3 on.  Note the small differences between Layer2 and Layer3.
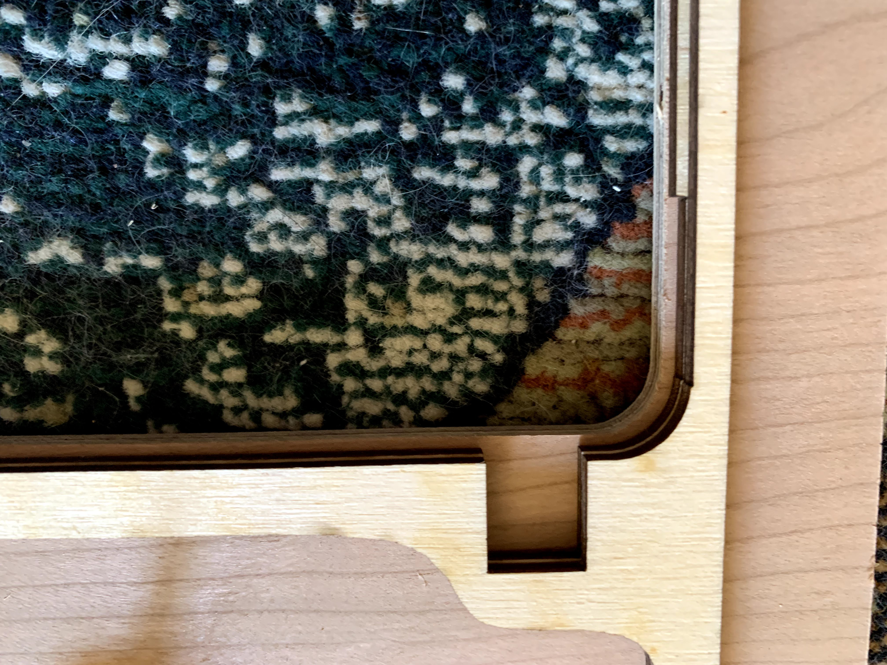
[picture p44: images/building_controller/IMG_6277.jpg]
<br>
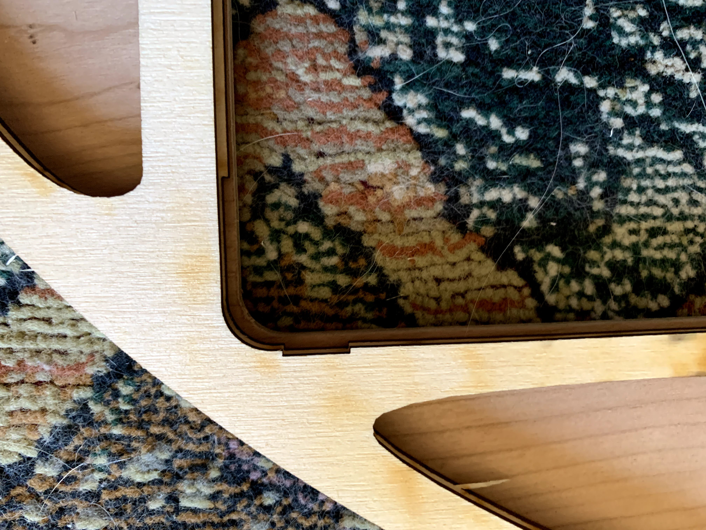
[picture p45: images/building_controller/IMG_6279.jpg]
<br>
<p>
<hr><hr>
Put the 4 Sensel Morphs in place.
NOTE: These pictures don't show it, but you should attach the four right-angle mini USB cables to the four Morphs.
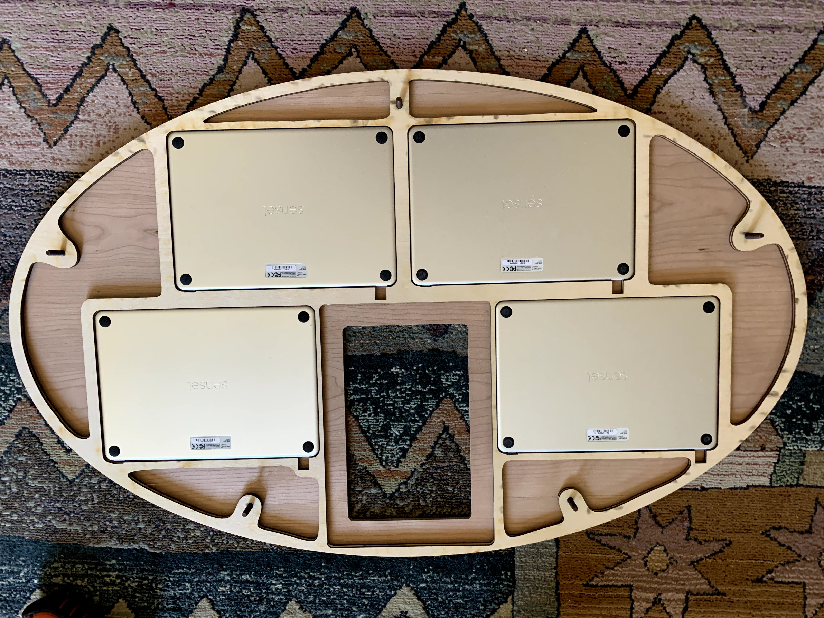
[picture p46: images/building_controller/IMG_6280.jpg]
<br>
<p>
<hr><hr>
Put Layer4 on.  Note how it overlaps the Morphs, keeping them in place.
NOTE: this picture doesn't show the cables that should already be connected to the Morphs.
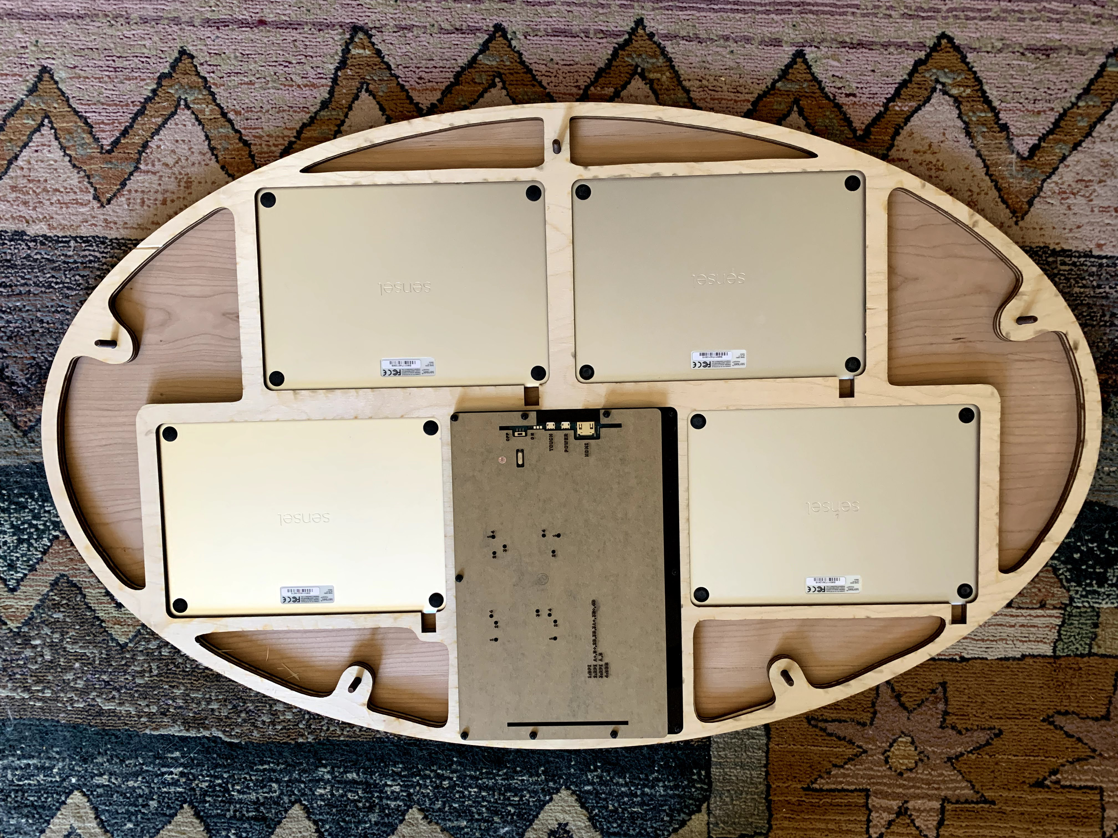
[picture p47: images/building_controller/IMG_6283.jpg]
<br>
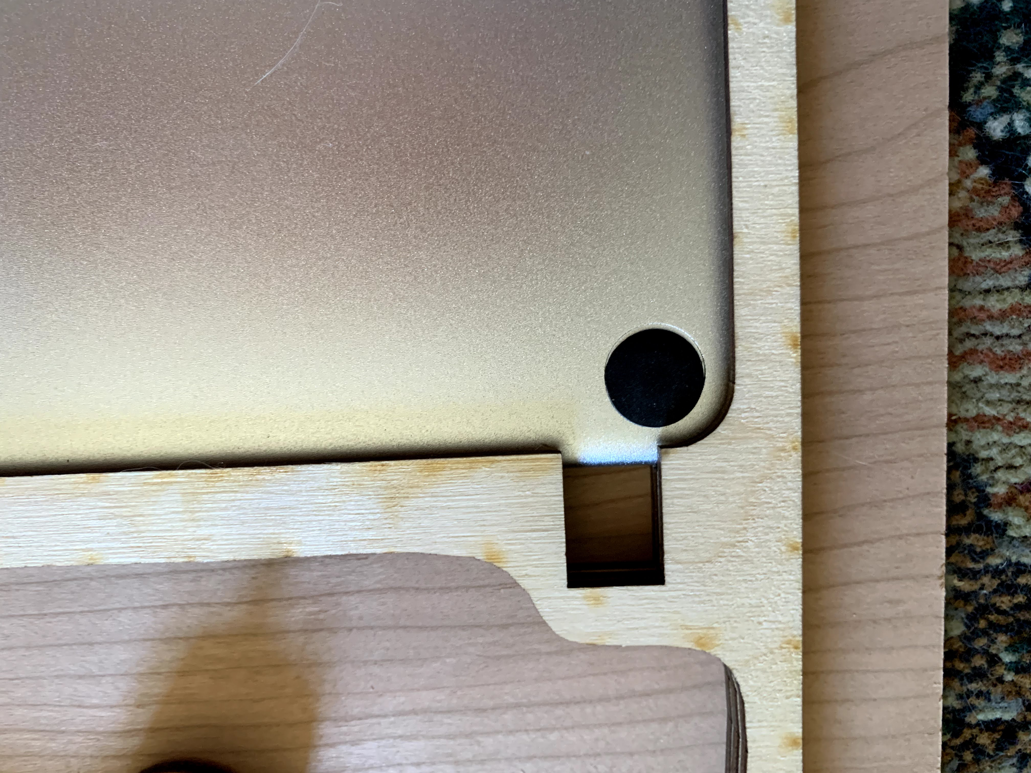
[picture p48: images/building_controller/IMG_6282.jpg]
<br>
<p>
<hr><hr>
Put the Waveshare 10.1" touchscreen into place, face down.
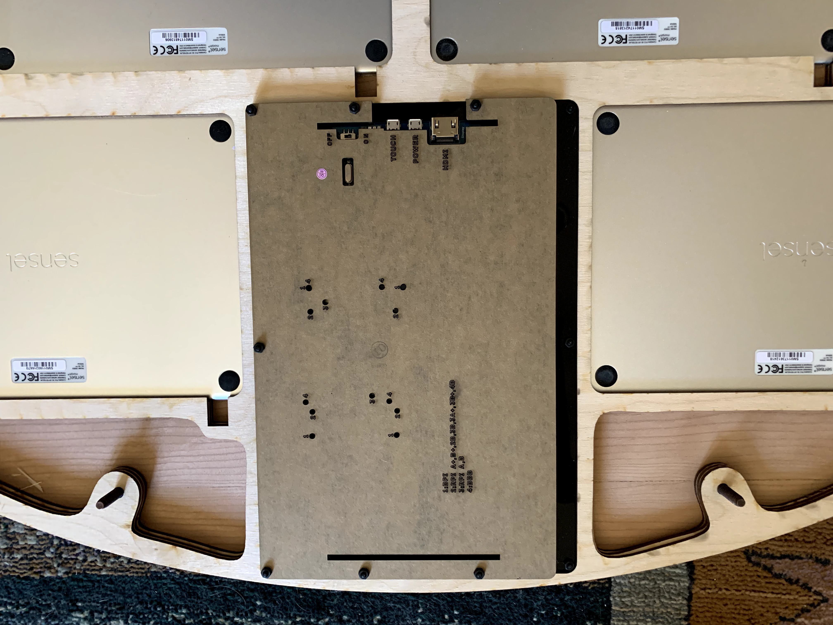
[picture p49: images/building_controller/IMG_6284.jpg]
<br>
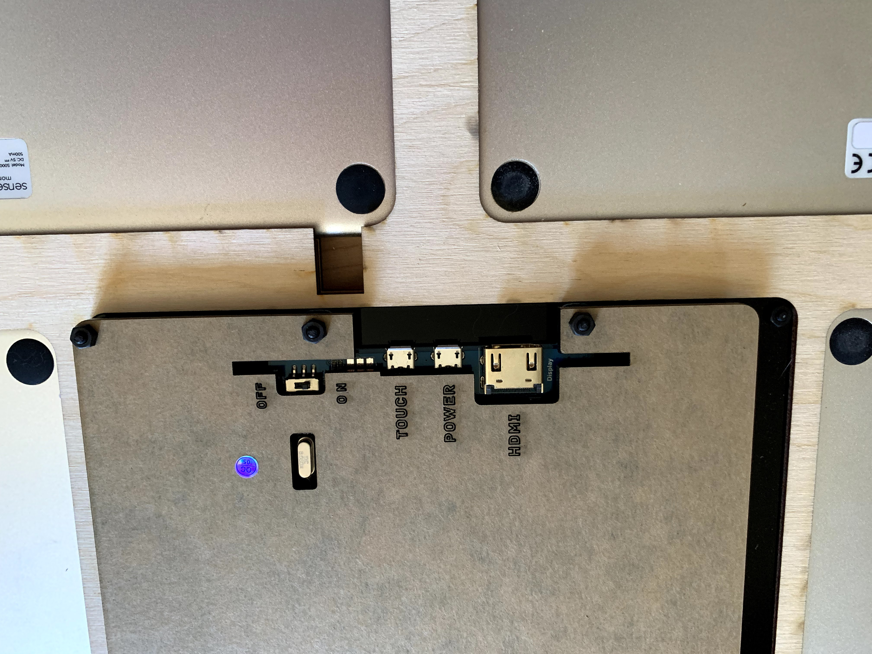
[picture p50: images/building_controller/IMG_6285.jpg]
<br>
<p>
Make sure the on/off switch on the touchscreen is on.
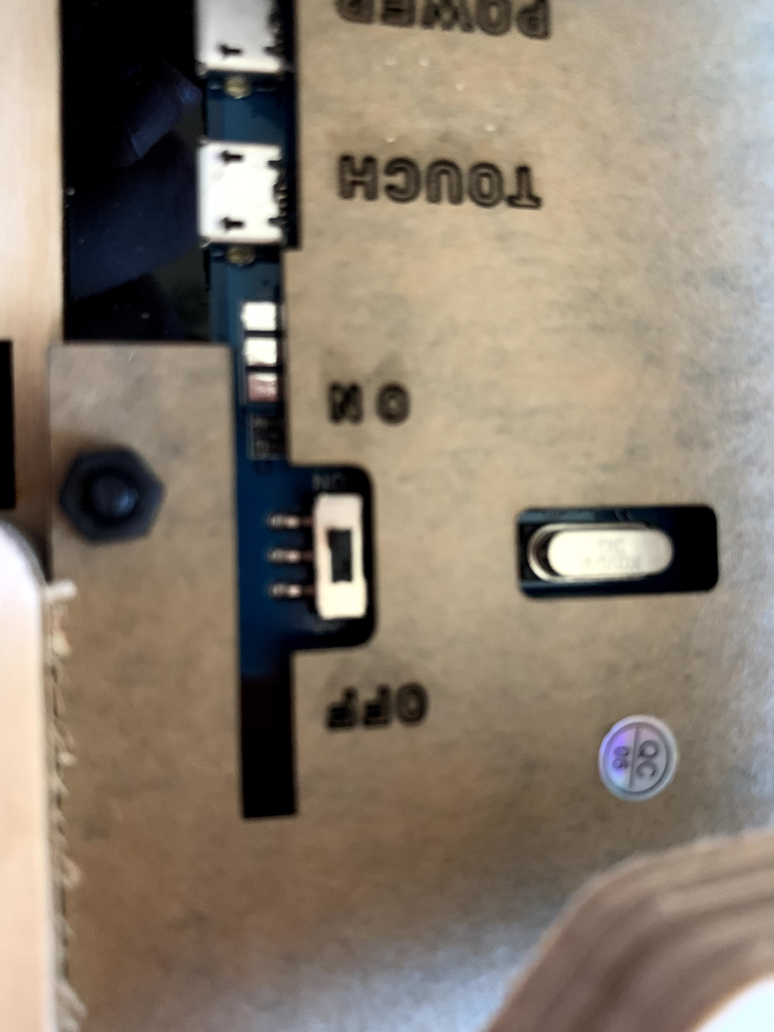
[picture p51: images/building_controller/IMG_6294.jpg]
<br>
<p>
<hr><hr>
Put Layer5 on.  Make sure all the cables are routed so that all the layers lay flat.
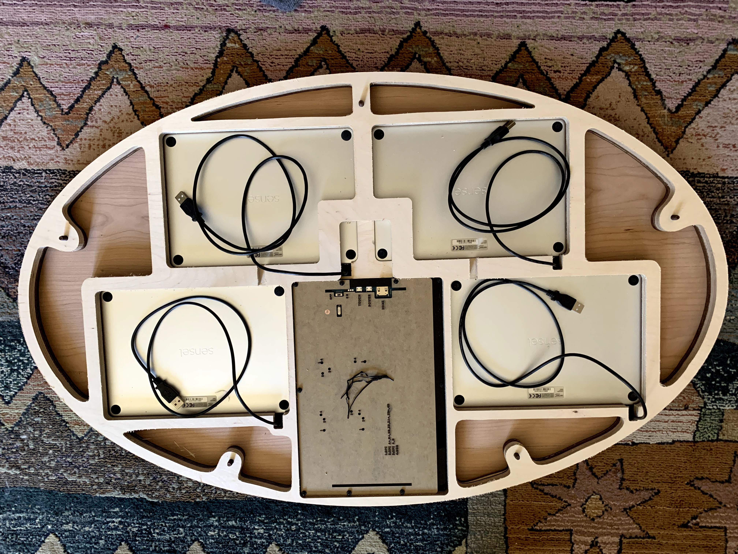
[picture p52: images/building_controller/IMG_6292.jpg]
<br>
<p>
<hr><hr>
Put Layer6 on.
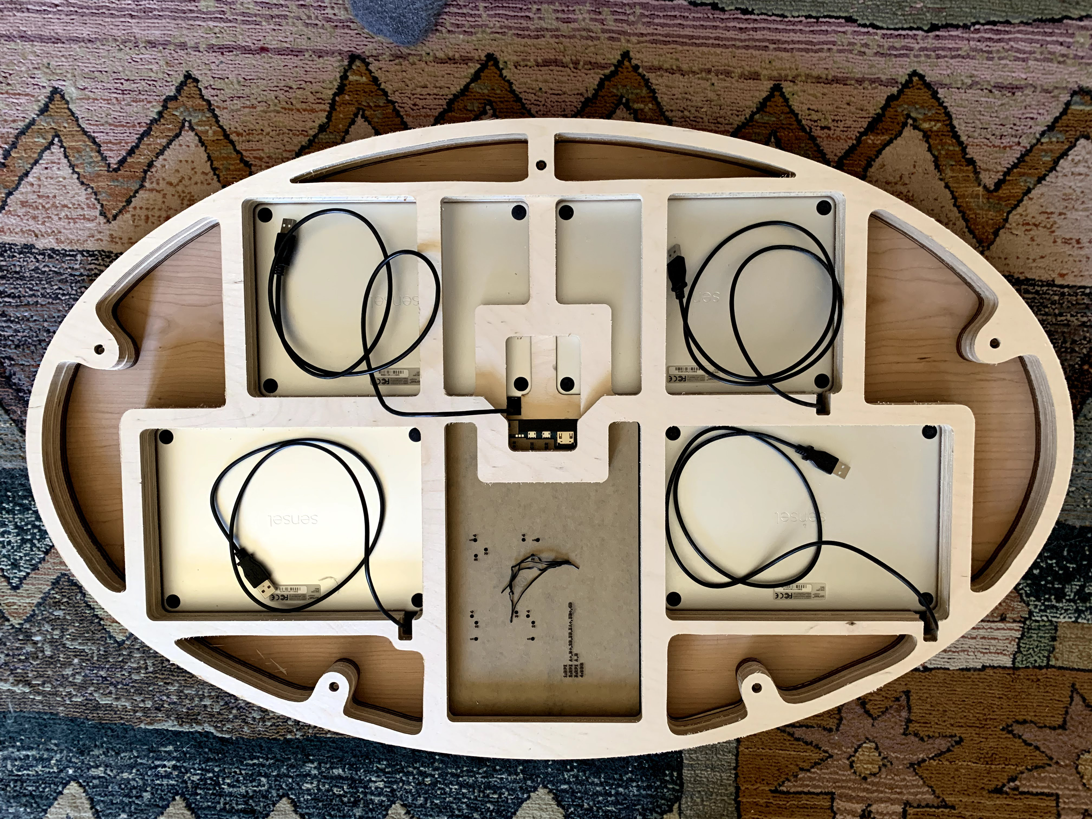
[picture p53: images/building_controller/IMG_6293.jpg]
<br>
<p>
Note how some of the cables are routed through gaps in Layer5.
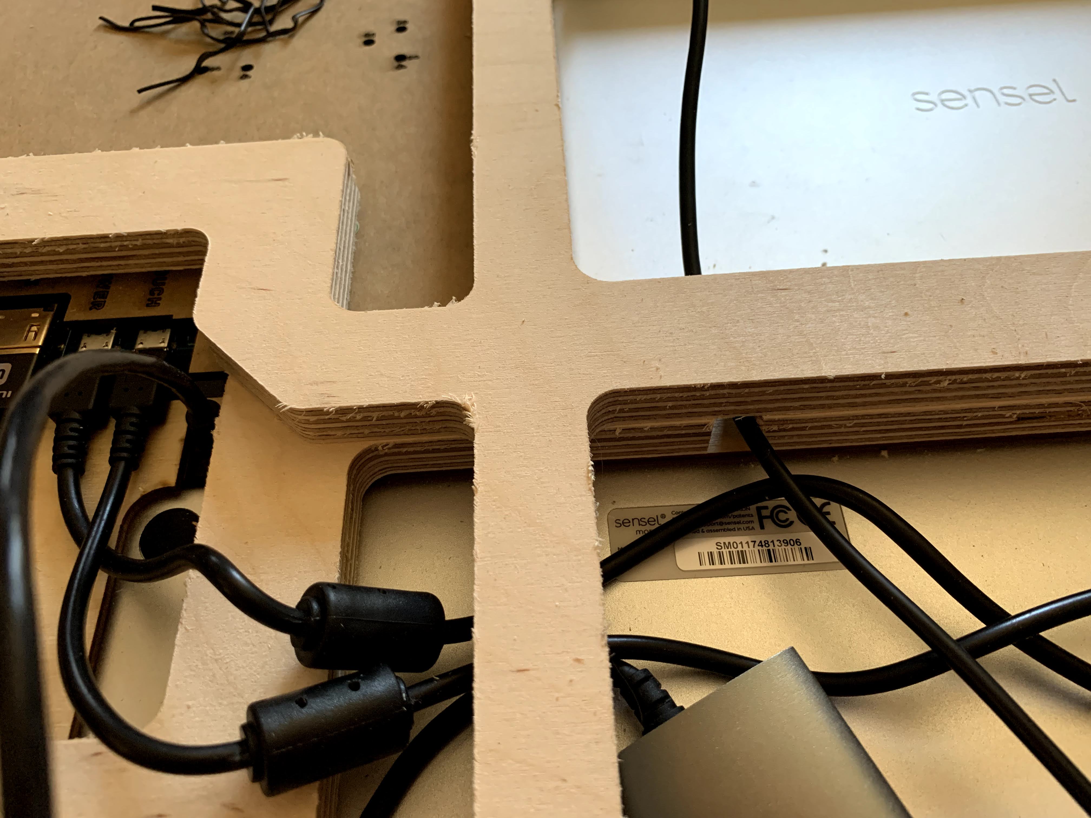
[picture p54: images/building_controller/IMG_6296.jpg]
<br>
<p>
<hr><hr>
Attach two 1-foot USB cables to the monitor, and connect them to one of the USB hubs, as shown.  Also attach the 3-foot HDMI cable to the monitor, as shown.
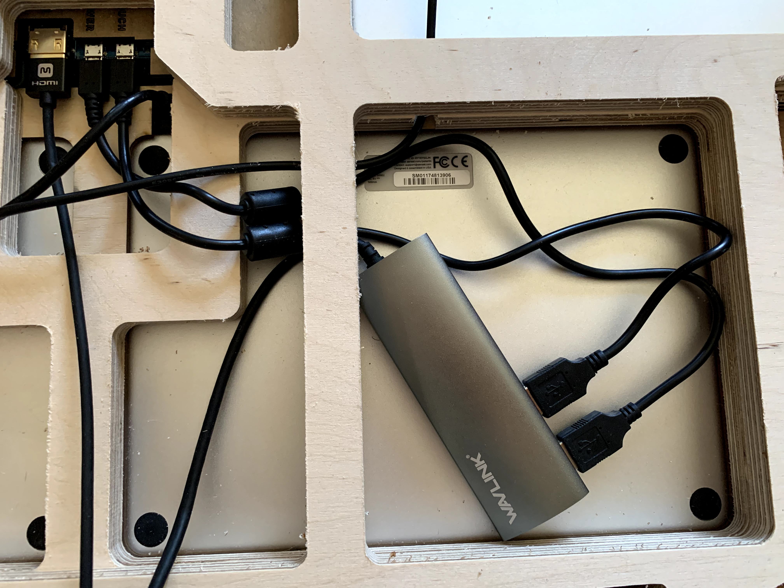
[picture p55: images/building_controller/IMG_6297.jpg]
<br>
<p>
<hr><hr>
Attach the four cables from the Morphs to the second USB hub, and route the cables so that all the layers are flat.  You may want to tape the cables down so they don't get in the way when you add the final layer.
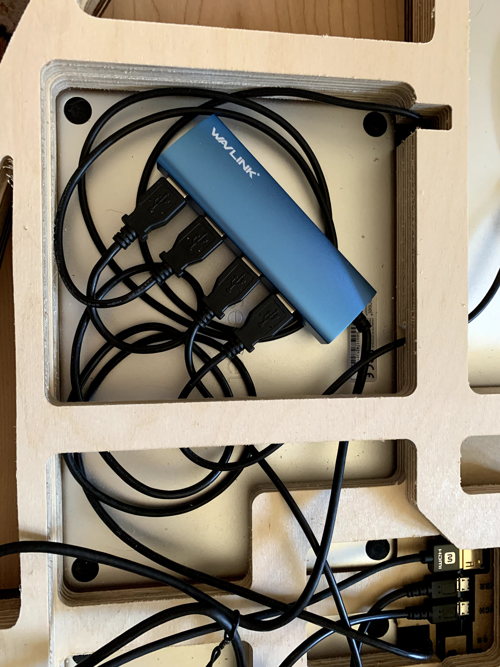
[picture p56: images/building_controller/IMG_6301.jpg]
<br>
<p>
<hr><hr>
This is a picture with everything in place, just before adding the final back layer.
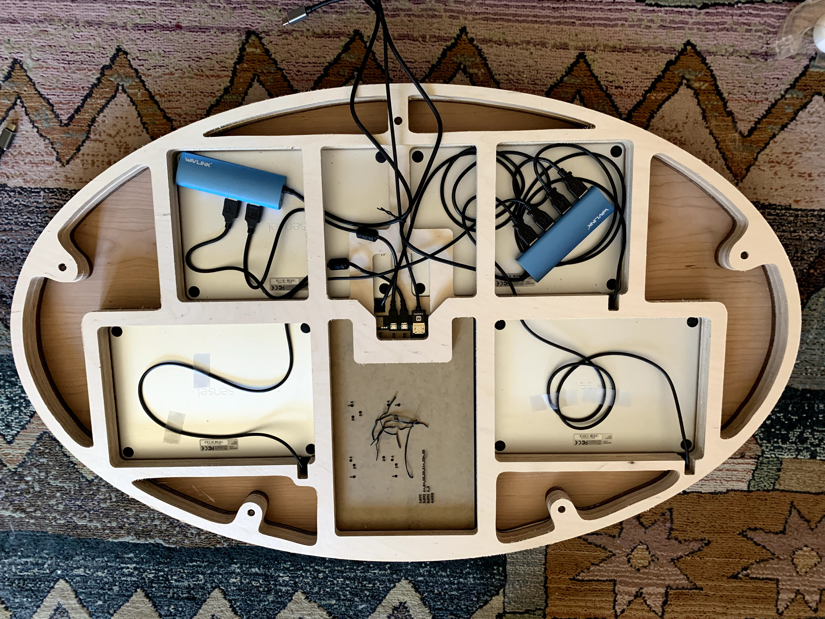
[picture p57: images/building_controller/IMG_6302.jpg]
<br>
<p>
<hr><hr>
Before you add Layer6, attach the 2 metal L-angle brackets to it, as shown, using short 1/4"-20 bolts.
Note their orientation carefully, in terms of which side the L is on, and which holes the bolts go through.
<p><br>
Then, add Layer6, routing the three cables (two USB cables and one HDMI cable) through its hole.
<p><br>
Finally, screw the bronze caps onto the 5 bolts.  It may be a snug fit.
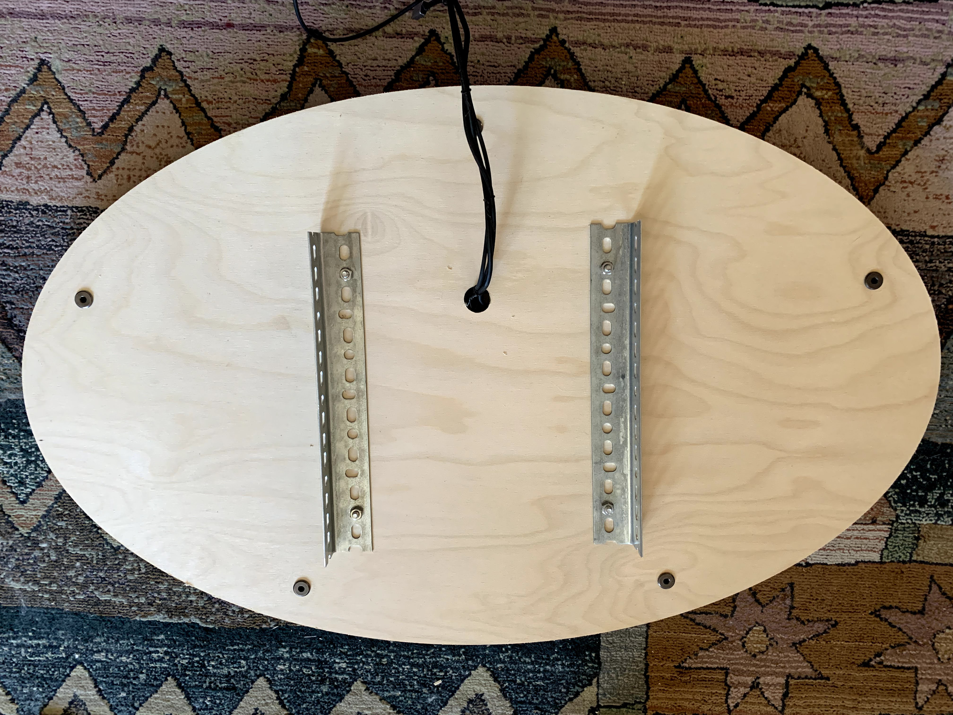
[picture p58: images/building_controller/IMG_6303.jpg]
<br>
<h2>You now have a Space Palette Pro Controller!</h2>

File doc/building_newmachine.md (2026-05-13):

<h1>Setting up Space Palette Pro on a new computer</h1>
These steps are designed for taking a new Windows 11 computer and configuring everything from scratch.
This is specific to the 2024 Asus NUC 970, but should be almost identical for most Windows computers.
<p>

<ol>

<li>When booting for the first time, keep pressing F2 until the BIOS setup comes up.  Go into the Power settings, and then select the Secondary Power Settings.  Change the "After Power Failure" setting to Power On.  Save and exit/reboot.

<li>Do the initial Windows setup and connect to a network.

<li>Change computer name to spacepalette{serialnum}.  It will reboot and install updates.

<li>When asked to log in, click on create a new account, and then "Get a new email address".
Use spacepalette{serialnum}@outlook.com / ThereIsNoPalette{serialnum}InSpace!

<li>Set up as a new PC, don't install anything else.

<li>Uninstall OneDrive.

<li>Forward email from spacepalette{serialnum}@outlook.com to me@timthompson.com

<li>Download and install Chrome, then sign in as spacepalette@gmail.com.  Let it create a passkey.  Do not turn on sync or anything else.

<li>In Chrome, go to remotedesktop.google.com and seleromet "Access My Computer".  Scroll down and "Set up remote access".  Install the remotedesktop extension in Chrome, and use spacepalette{serialnum} for the computer name.

<li>Set Chrome as the default browser.  Set chrome startup to "where you left off"

<li>Download and install Windows updates.

<li>In Windows->Settings->Accounts->Sign-in options, under "Additional settings" turn off "...only allow Windows Hello...", and set "If you've been away, when should Windows..." to "Never"

<li>Use Win-R to run netplwiz.exe, and set it up to automatically log in with spacepalette{serialnum}@outlook.com

<li>Reboot to make sure autologon works.
<li>In Windows Settings, set System->Power->Power Mode to Best Performance
<li>In Windows Settings, set System->Power->Screen timeouts to Never
<li>Increase mouse pointer size
<li>Right-click on desktop and don't show desktop icons.
<li>Set display background to solid color.

<li>Show filename extensions in Explorer
<li>Copy T:\tjt\media\spacepalettepro\palette_installers to Downloads
<li>Execute bginfo64.exe and load palette.bgi
<li>Install sharpkeys to remap capslock key.
<li>Install WSL and Ubuntu, set root to same password as Windows login
<li>Install Github Desktop
<li>Install Git for Windows
<li>Install github (gh) CLI, i.e. gh_*.msi
<li>mkdir %USERPROFILE%\Github
<li>execute "gh auth login"
<li>cd %USERPROFILE%\Github, gh repo clone vizicist/palette
<li>cd %USERPROFILE%\Github, gh repo clone vizicist/spacepalettepro
<li>Install release/palette_{release}_win_setup.exe
<li>Install release/palette_{release}_data_default.exe
<li>In your Environment Variables:
<br>- Add %USERPROFILE%\Github\palette\scripts to your PATH
<br>- Add C:\Program Files\Git\bin to your PATH
<br>- Add C:\Program Files\Git\usr\bin to your PATH
<br>- Add %USERPROFILE%\mingw64\bin to your PATH (adjust path if installed elsewhere)
<br>- Add the following new environment variables:
<br>      PALETTE=%LOCALAPPDATA%\Programs\Palette   # palette_win_setup should have already added
<br>      PALETTE_DATAROOT=%LOCALAPPDATA%\Palette   # palette_win_setup should have already added
<br>      PALETTE_SOURCE=%USERPROFILE%\Github\palette
<li>Install mingw64 to get the gcc compiler.
The last time I installed it from https://github.com/niXman/mingw-builds-binaries, and it may be necessary to download
the "online installer" and execute it from the Explorer, selecting "more info" to allow installation of an unsigned pack
age.  The options I used are: version 13.2.0, architecture 64 bit, thread model posix, rev1, ucrt.
The version of gcc I'm using gives this output from 'gcc --version' -
gcc (x86_64-win32-seh-rev1, Built by MinGW-Builds project) 14.2.0

<li>Install Python 3.{latest} from python.org (NOT windows store), and add it to PATH, and disable PATH limit
<li>Install InnoSetup
<li>Install SenselApp0.19.32
<li>Install gvim (create .bat files)
<li>Install 7zip
<li>Install Go
<li>In palette repo, run go mod tidy
<li>Install Visual Studio Code, install vim and go extensions, update to latest
<li>Some of the installers (e.g. Visual Studio) seem to require a real HDMI to be plugged in
<li>Install Visual Studio Community edition, selecting "Desktop development with C++"
<li>Install Resolume 7, license it, Enable OSC input, set Video Plugin dir to %LOCALAPPDATA%\Programs\Palette\ffgl
<li>In Resolume, open %LOCALAPPDATA%\Palette\data_default\config\PaletteDefault.avc
<li>Create c:\Program Files\Common Files\VST2 and VST3
<li>Install Drumnet
<li>Install Omnisphere and license it with spacepalette{serialnum}@outlook.com
<li>Install Plogue Bidule (version 9784 or later), enable OSC server
<li>Install LoopBe, disable shortcut protection, expand to 16 ports
<li>Run scripts/multitouch_disable.bat
<li>Run scripts/setup_onboot.bat (as administrator)
<li>With touchscreen connected, Control Panel->small icons->Tablet PC Settings, Setup, Touch Settings.
<li>In Display Settings, put touchscreen to left of main screen, and Portrait Flipped.
<li>cd palette\build\windows ; build & install
<li>palette setboot global.guisize palette
</ol>

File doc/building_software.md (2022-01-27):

<h1>Building the Software of the Space Palette Pro</h1>
These are the steps to install and configure all the necessary software for a full-blown (visuals and sound) Space Palette Pro.  This procedure is much more complex than it is for a visuals-only Space Palette Pro.  If you only want to do visuals, the much simpler installation procedure is at
<a href="https://github.com/vizicist/palette/blob/main/doc/using_resolume.md">https://github.com/vizicist/palette/blob/main/doc/using_resolume.md</a>
<p>

<ol>
<li>Install LoopBe30 from <a href="https://www.nerds.de/en/order.html">https://www.nerds.de/en/order.html</a><br>
    <ul>
    <li>Use LoopBe30 tray item to expand "ports after reboot" to 16
    <li>Turn off "Enable Shortcut Detection"
    <li>Reboot
    </ul>
<li>Install ASIO4ALL from <a href="https://asio4all.org">https://asio4all.org</a>.
<li>Install Palette
    <ul>
    <li>Use the desired (usually the latest) install package in
    <a href="https://github.com/vizicist/palette/tree/main/release">https://github.com/vizicist/palette/tree/main/release</a>
    </ul>
<li>Create (if it doesn't exist already) this
directory: c:\users\public\documents\vstplugins64.
In the Windows Explorer, it should appear as
C: > Users > Public > Public Documents > vstplugins64
<li>Install Omnisphere 2 in c:\users\public\documents\vstplugins64
<li>Install Battery 4 in c:\users\public\documents\vstplugins64
<li>Install Battery 4 Factory Library
<li>Install Plogue Bidule:
    <ul>
    <li>In Edit->Preferences->VST set the VST plugin path to c:\users\public\documents\vstplugins64
    <li>In Tools->Osc Server, enable OSC 
    <li>Open %LOCALAPPDATA%\Palette\config\palette.bidule
    <li>Make sure Battery 4 instances can send audio, fixing the audio device
if necessary to make sure there is minimal latency when playing back drum hits.
This may require using the Bidule GUI to set the audio output device to a suitably-configured ASIO device.
    <li>Authorize Omnisphere 2 by double-clicking on one of its instances in Bidule, and following the instructions.  The window with the authorization instructions may be hidden behind other windows.
    <li>Restart Bidule, verify that Omnisphere is authorized by double-clicking on one of the Omnisphere instances and verifying that it no longer shows the auuthorization screen.
    </ul>
<li>Install Resolume 7 (Avenue)  
    <ul>
    <li>In Avenue->Preferences->Video, add C:\Program Files\Palette\ffgl
    <li>In Avenue->Preferences->OSC, enable OSC Input on port 7000
    <li>Quit and restart Resolume
    <li>Verify that Palette plugin is seen in Sources under Generators
    <li>In Composition->Open, open %LOCALAPPDATA%\Palette\config\PaletteABCD.avc, then Quit
    <li>In Output->Fullscreen, set the Palette's main monitor to fullscreen
    </ul>
<li>Install SenselApp
    <ul>
    <li>Verify that your Morphs are seen, and updated to the latest firmware.
    <li>If you are using 4 Morphs (e.g. a full-blown Space Palette Pro controller), make sure their serial numbers are in %LOCALAPPDATA%\Palette\config\morphs.json and are associated with the desired pad letters (A,B,C,D)
    </ul>
<li>Install Git from <a href="https://gitforwindows.org">https://gitforwindows.org</a><br>
    <ul>
    <li>Accept all the defaults
    <li>Add c:\program files\git\usr\bin to the value of PATH in System Properties->Environment Variables
    <li>Optional: install GitHub Desktop from <a href="https://desktop.github.com">https://desktop.github.com</a>
    </ul>
</ol>
If you are using a touchscreen monitor for the preset selector GUI, then do these steps:
<p>
<ol>
<li>Use Windows Settings->Display to adjust the monitor settings
    <ul>
    <li>Adjust touchscreen monitor for Resolution = 800x1280, Orientation = Portrait (flipped)
    <li>Put console monitor on the right, touchscreen monitor in the middle, and the external monitor (or oval monitor) on the left.
    </ul>
<li>Make sure Windows knows which monitor is the touchscreen
    <ul>
    <li>Go to the Windows Control Panel (the old one)
    <li>change the "View by" to "Small icons"
    <li>In "Tablet PC Settings", select "Setup..." and then "Touch Input",
      following the instructions to select the touchscreen monitor as the touch screen
    <li> If you don't see "Tablet PC Settings", it means the touchscreen monitor
      isn't connected.
    </ul>
</ol>

You should now be able to use the Palette as described in
<a href="https://github.com/vizicist/palette/blob/main/doc/starting_and_using.md">https://github.com/vizicist/palette/blob/main/doc/starting_and_using.md</a>

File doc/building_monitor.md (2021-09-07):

<h1>Building the Monitor of the Space Palette Pro</h1>
Use the longer 1.97-inch connector bolts, and put the first layer face-down.
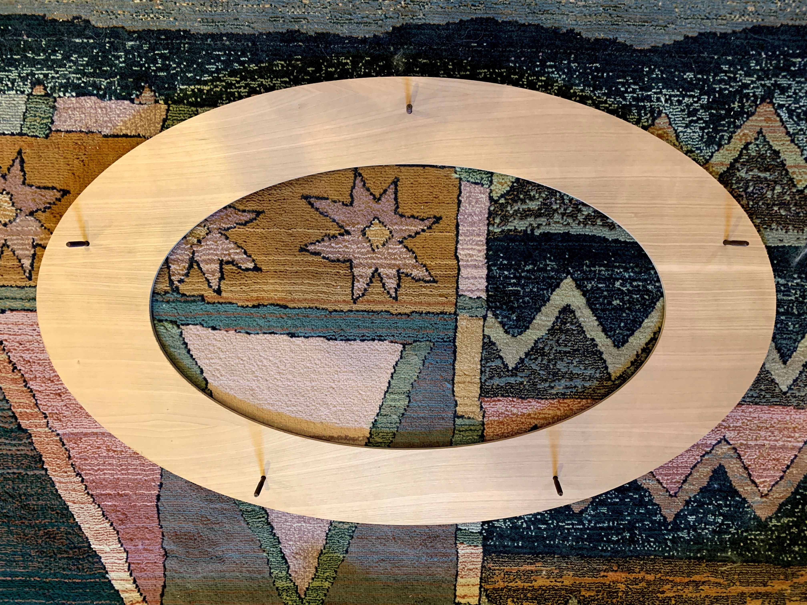
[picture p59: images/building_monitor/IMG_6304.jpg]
<br>
<br>
Put the monitor in place.
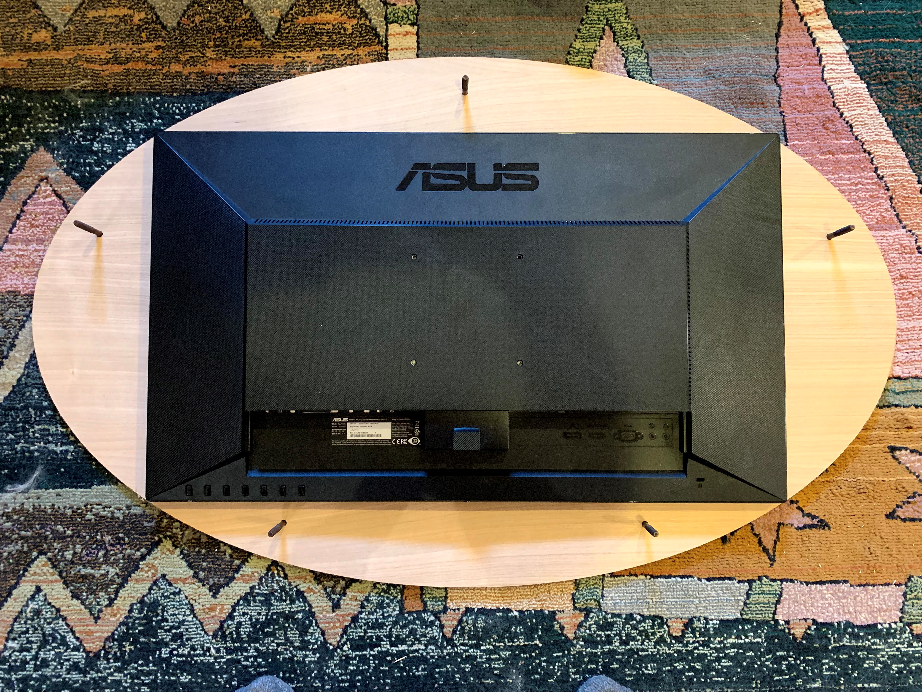
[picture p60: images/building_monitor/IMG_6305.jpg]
<br>
<br>
The next two layers are each composed of four separate pieces arranged around the monitor.
The fit is tight, and assumes the specific model of monitor identified in the parts list.
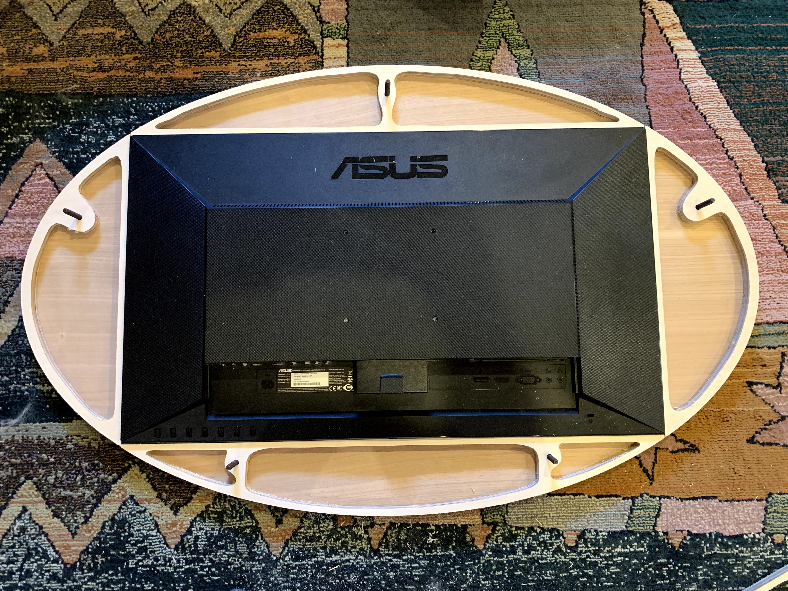
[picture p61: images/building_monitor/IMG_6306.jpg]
<br>
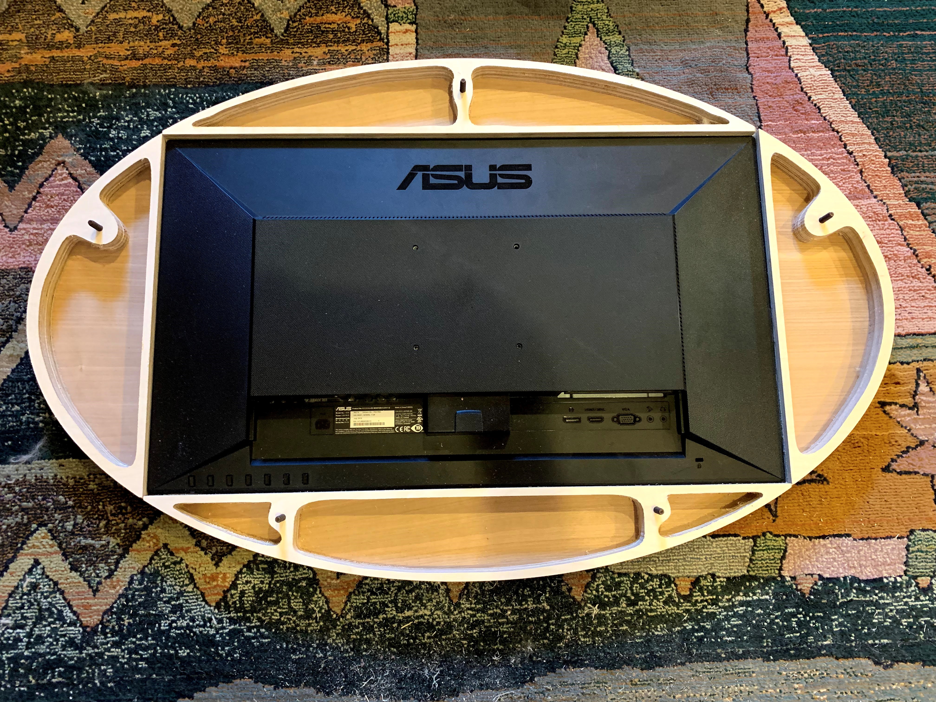
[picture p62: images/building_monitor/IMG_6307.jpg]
<br>
<br>
The next layer is three-sided, the open side should be at the bottom.
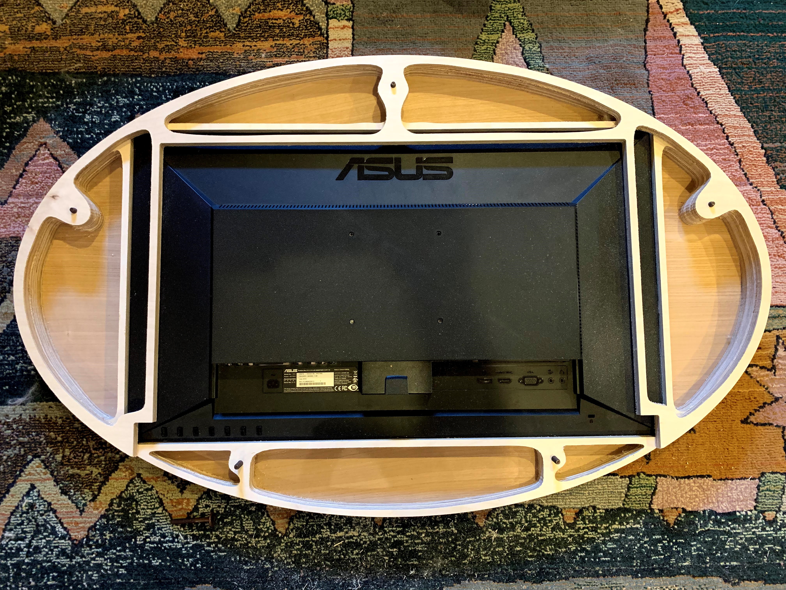
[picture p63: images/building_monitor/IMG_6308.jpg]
<br>
<br>
When adding the BaseBack layer, be sure to get the left/right orientation correct.
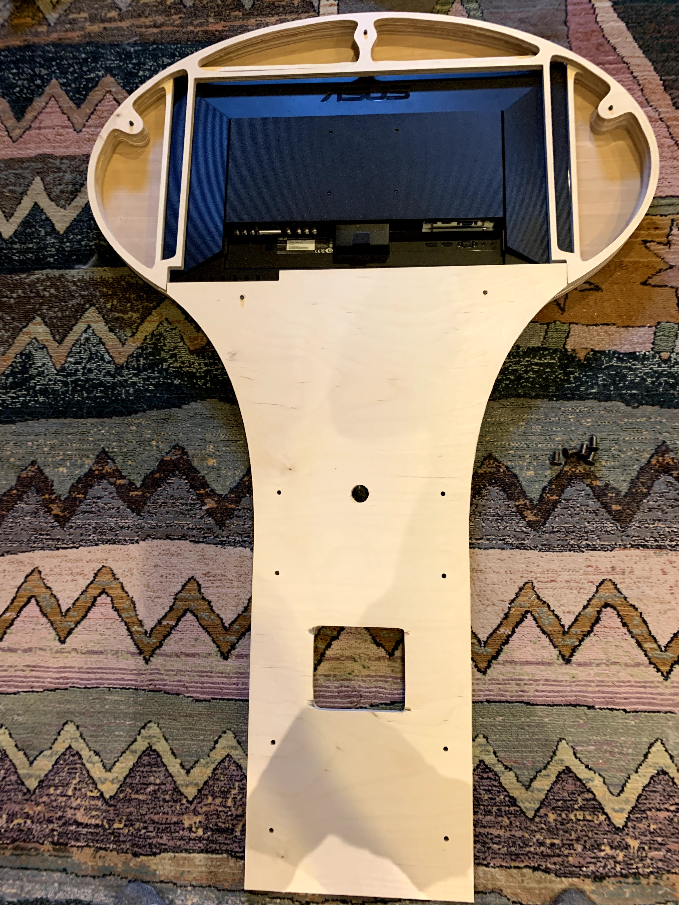
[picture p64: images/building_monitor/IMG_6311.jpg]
<br>
<br>
Again, be sure to get the left/right orientation correct, so that the buttons toward
the left side of the monitor can be accessed.
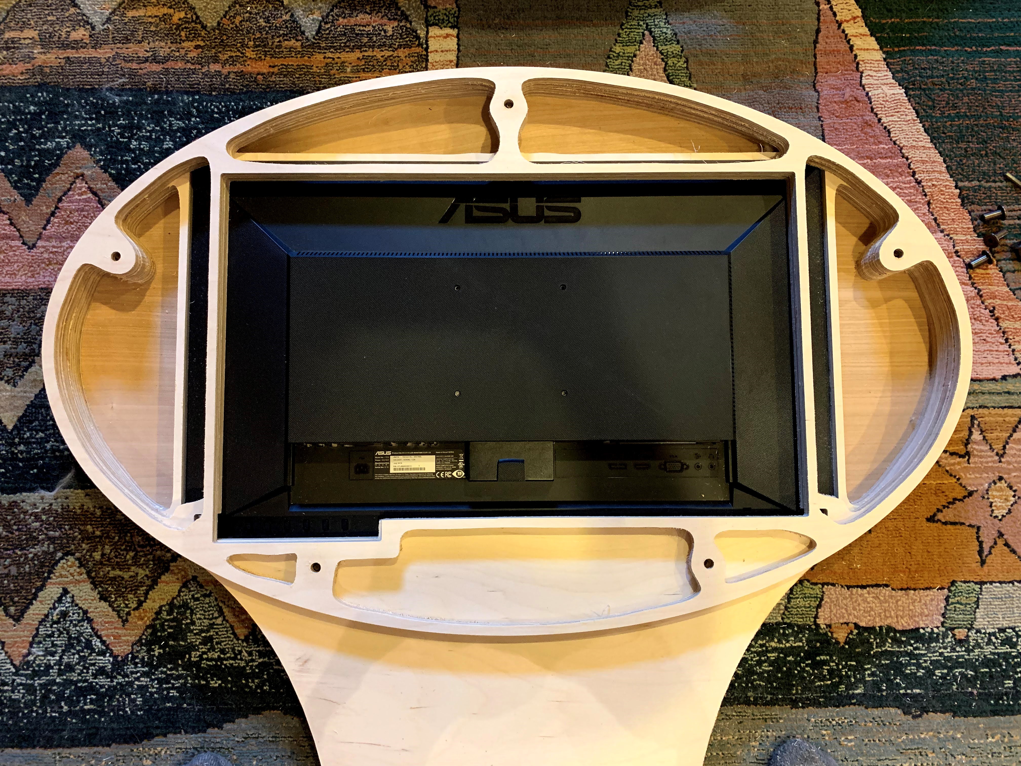
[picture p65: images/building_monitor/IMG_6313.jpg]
<br>
<br>
Add the final back.
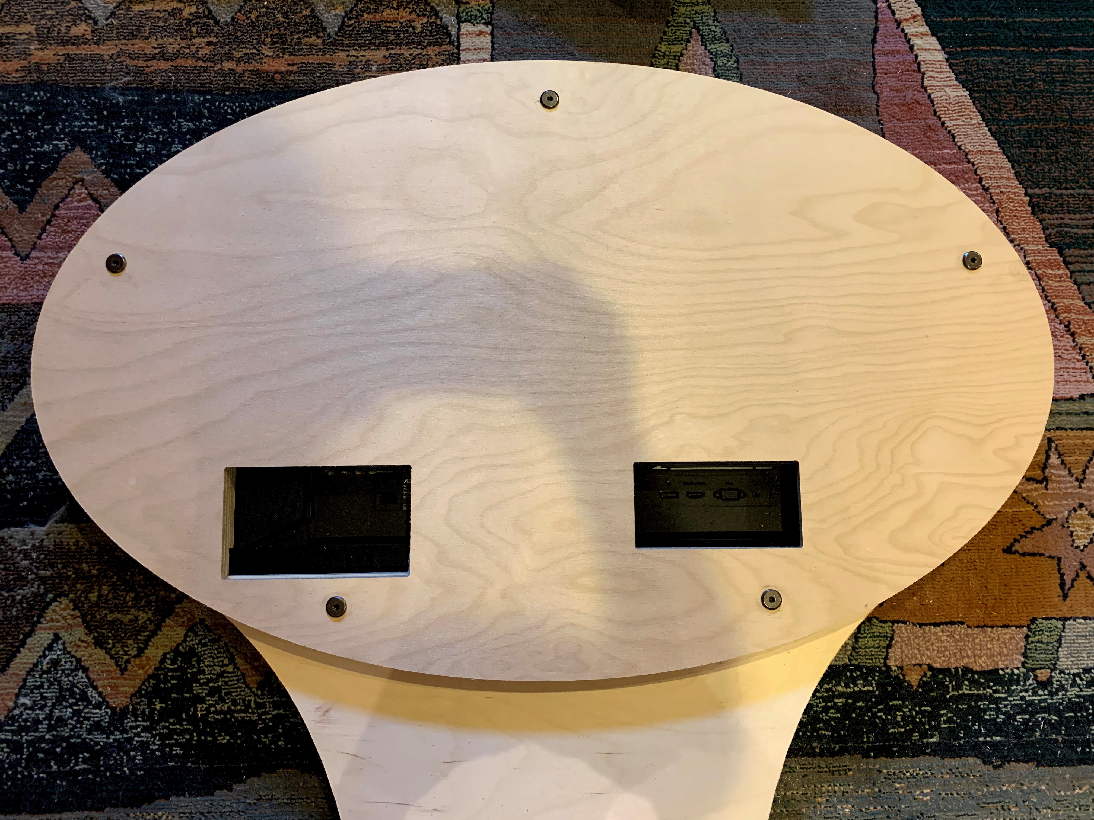
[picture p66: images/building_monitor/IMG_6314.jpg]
<br>

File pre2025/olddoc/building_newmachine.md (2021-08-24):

<h1>Building the Software of the Space Palette Pro</h1>
These steps are designed for taking a new Windows 10 computer and configuring everything from scratch.
<p>

<ol>
<li>Change computer name to palette{serialnum}
<li>Reboot, put in USB wifi, connect to network
<li>Use Microsoft account to log in, install Windows udpates
<li>Install Chrome
    - Optionally: enable google remote desktop.  This requires a Google account, and is very useful for remote installation and monitoring.
<li>Follow the instructions for <a href="building_software.md">building the software</a>.
</ol>

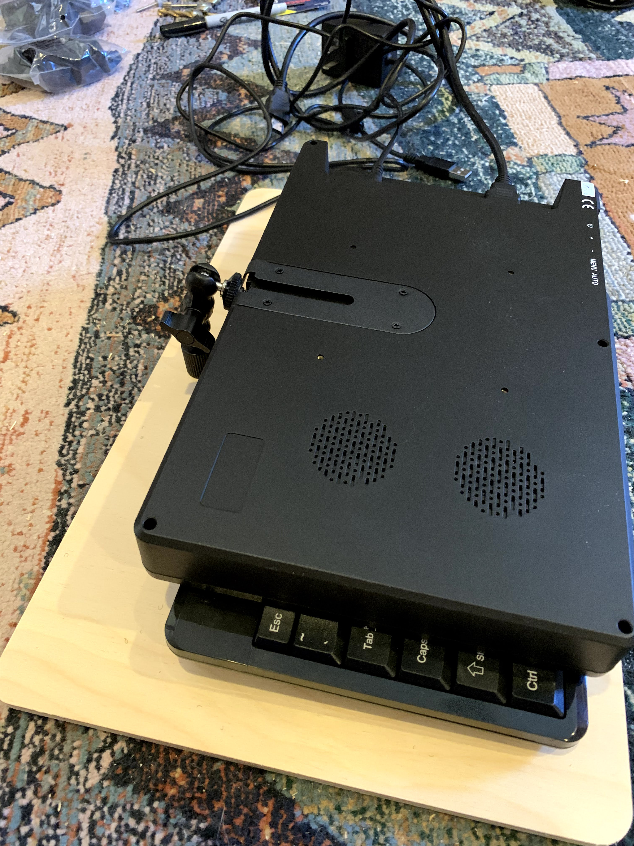
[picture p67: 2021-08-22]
images/building_base/IMG_6353.jpg

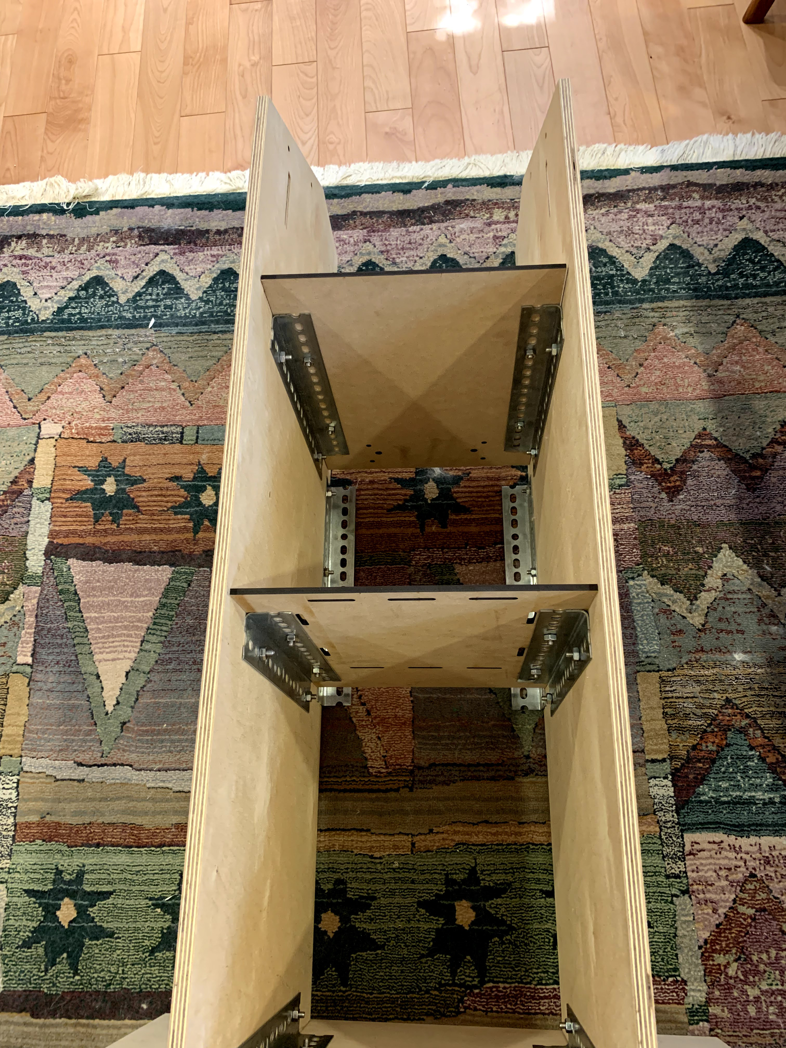
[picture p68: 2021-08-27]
images/building_base/IMG_6584.jpg

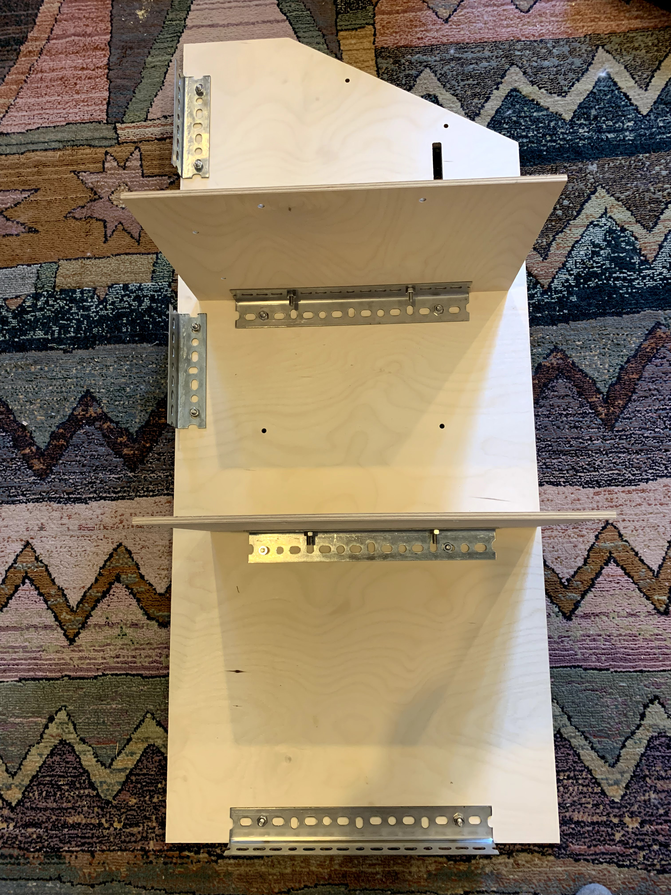
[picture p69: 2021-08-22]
images/building_base/IMG_6327.jpg

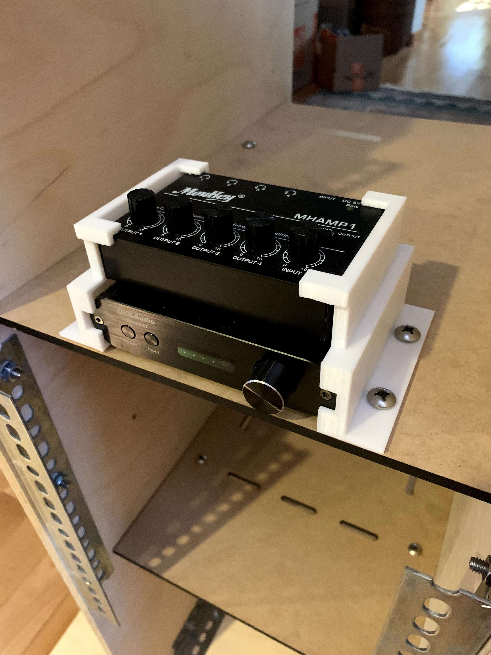
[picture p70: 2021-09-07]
pre2025/images/building_base/IMG_6599.jpg

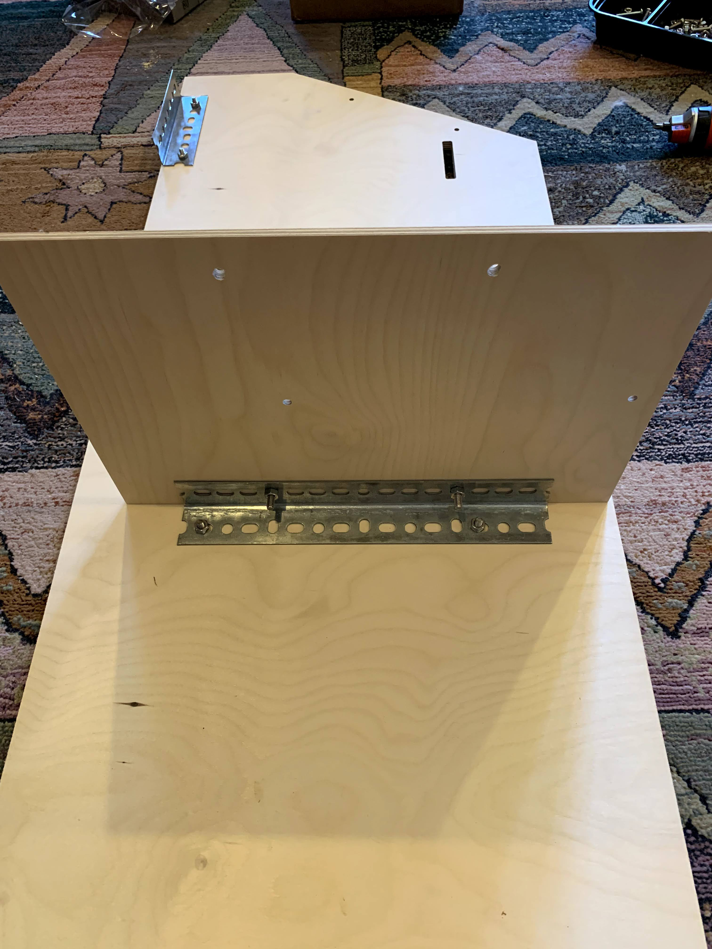
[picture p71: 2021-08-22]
images/building_base/IMG_6325.jpg

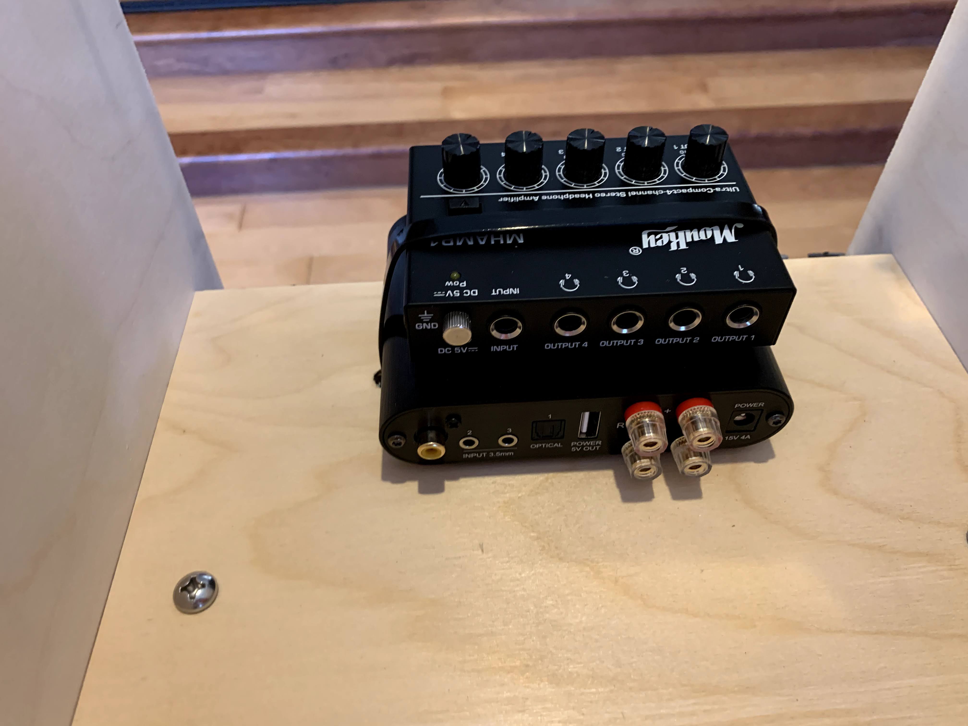
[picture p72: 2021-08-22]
images/building_base/IMG_6342.jpg

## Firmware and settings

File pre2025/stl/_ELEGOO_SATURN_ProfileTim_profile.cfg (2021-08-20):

__resin:normal
antiAliasLevel:4
bAntiAliasLevelEditable:0
bAntiAliasing:1
bBottomInnerOutterCircleOffsetEnable:0
bBuildAreaOffsetEnable:0
bDisplayCorrectEnable:0
bImageBlur:1
bImageBlurPixelEditable:1
bImageMask:0
bInnerOutterCircleOffsetEnable:0
bLockXYSizeRatio:1
bSurfaceRoughEditable:0
bottomEdgeExposureMM:0
bottomEdgeExposureTimeS:4
bottomExposureTimeStrategy:0
bottomInnerCircleOffset:0
bottomLayerCount:5
bottomLayerDropHeight2:0
bottomLayerDropSpeed:210
bottomLayerDropSpeed2:0
bottomLayerExposureTime:30
bottomLayerLiftHeight:10
bottomLayerLiftHeight2:0
bottomLayerLiftSpeed:70
bottomLayerLiftSpeed2:0
bottomLightIntensityPWM:255
bottomLightOffTime:0
bottomOutterCircleOffset:0
bottomRestTimeAfterLift:0
bottomRestTimeAfterRetract:0.5
bottomRestTimeBeforeLift:0
buildAreaOffsetBottom:0
buildAreaOffsetLeft:0
buildAreaOffsetRight:0
buildAreaOffsetTop:0
circleParityDifference:0
currProfile:ProfileTim
displayCorrectLeftBottomX:0
displayCorrectLeftBottomY:0
displayCorrectLeftTopX:0
displayCorrectLeftTopY:0
displayCorrectRightBottomX:0
displayCorrectRightBottomY:0
displayCorrectRightTopX:0
displayCorrectRightTopY:0
edgeExposureMM:0
edgeExposureTimeS:4
endGcode:
fillDensity:30
fillPattern:None
imageBlurPixel:2
imageMaskFile:
innerCircleOffset:0
layerGcode:
layerHeight:0.05
lightOffTime:8.5
machineDepth:120
machineHeight:200
machineType:ELEGOO SATURN
machineWidth:192
maskGrayScaleUnit:4
maxGreyLevel:255
minGreyLevel:95
normalExposureTime:5
normalLayerDropHeight2:0
normalLayerDropSpeed:210
normalLayerDropSpeed2:0
normalLayerLiftHeight:10
normalLayerLiftHeight2:0
normalLayerLiftSpeed:70
normalLayerLiftSpeed2:0
normalLightIntensityPWM:255
normalRestTimeAfterLift:0
normalRestTimeAfterRetract:0.5
normalRestTimeBeforeLift:0
outterCircleOffset:0
printWaitMode:0
projectType:LCD_mirror
resinDensity:1.1
resinPrice:30
resinUnit:$/L
resolutionX:3840
resolutionY:2400
shellThickness:1.2
sliceExportPart:0
startGcode:
surfaceRoughLevel:1
transitionLayerCount:10
transitionLayerType:0
zSlowUpDistance:0
@@ProfileTim@@__resin:"normal"
@@ProfileTim@@antiAliasLevel:"4"
@@ProfileTim@@bAntiAliasLevelEditable:"0"
@@ProfileTim@@bAntiAliasing:"1"
@@ProfileTim@@bBottomInnerOutterCircleOffsetEnable:"0"
@@ProfileTim@@bBuildAreaOffsetEnable:"0"
@@ProfileTim@@bDisplayCorrectEnable:"0"
@@ProfileTim@@bImageBlur:"1"
@@ProfileTim@@bImageBlurPixelEditable:"1"
@@ProfileTim@@bImageMask:"0"
@@ProfileTim@@bInnerOutterCircleOffsetEnable:"0"
@@ProfileTim@@bLockXYSizeRatio:"1"
@@ProfileTim@@bSurfaceRoughEditable:"0"
@@ProfileTim@@bottomEdgeExposureMM:"0"
@@ProfileTim@@bottomEdgeExposureTimeS:"4"
@@ProfileTim@@bottomExposureTimeStrategy:"0"
@@ProfileTim@@bottomInnerCircleOffset:"0"
@@ProfileTim@@bottomLayerCount:"5"
@@ProfileTim@@bottomLayerDropHeight2:"0"
@@ProfileTim@@bottomLayerDropSpeed:"210"
@@ProfileTim@@bottomLayerDropSpeed2:"0"
@@ProfileTim@@bottomLayerExposureTime:"30"
@@ProfileTim@@bottomLayerLiftHeight:"10"
@@ProfileTim@@bottomLayerLiftHeight2:"0"
@@ProfileTim@@bottomLayerLiftSpeed:"70"
@@ProfileTim@@bottomLayerLiftSpeed2:"0"
@@ProfileTim@@bottomLightIntensityPWM:"255"
@@ProfileTim@@bottomLightOffTime:"0"
@@ProfileTim@@bottomOutterCircleOffset:"0"
@@ProfileTim@@bottomRestTimeAfterLift:"0"
@@ProfileTim@@bottomRestTimeAfterRetract:"0.5"
@@ProfileTim@@bottomRestTimeBeforeLift:"0"
@@ProfileTim@@buildAreaOffsetBottom:"0"
@@ProfileTim@@buildAreaOffsetLeft:"0"
@@ProfileTim@@buildAreaOffsetRight:"0"
@@ProfileTim@@buildAreaOffsetTop:"0"
@@ProfileTim@@circleParityDifference:"0"
@@ProfileTim@@currProfile:"Profile"
@@ProfileTim@@currProfileName:"ProfileTim"
@@ProfileTim@@displayCorrectLeftBottomX:"0"
@@ProfileTim@@displayCorrectLeftBottomY:"0"
@@ProfileTim@@displayCorrectLeftTopX:"0"
@@ProfileTim@@displayCorrectLeftTopY:"0"
@@ProfileTim@@displayCorrectRightBottomX:"0"
@@ProfileTim@@displayCorrectRightBottomY:"0"
@@ProfileTim@@displayCorrectRightTopX:"0"
@@ProfileTim@@displayCorrectRightTopY:"0"
@@ProfileTim@@edgeExposureMM:"0"
@@ProfileTim@@edgeExposureTimeS:"4"
@@ProfileTim@@endGcode:""
@@ProfileTim@@fillDensity:"30"
@@ProfileTim@@fillPattern:"None"
@@ProfileTim@@imageBlurPixel:"2"
@@ProfileTim@@imageMaskFile:""
@@ProfileTim@@innerCircleOffset:"0"
@@ProfileTim@@layerGcode:""
@@ProfileTim@@layerHeight:"0.05"
@@ProfileTim@@lightOffTime:"8.5"
@@ProfileTim@@machineDepth:"120"
@@ProfileTim@@machineHeight:"200"
@@ProfileTim@@machineType:"ELEGOO SATURN"
@@ProfileTim@@machineWidth:"192"
@@ProfileTim@@maskGrayScaleUnit:"4"
@@ProfileTim@@maxGreyLevel:"255"
@@ProfileTim@@minGreyLevel:"95"
@@ProfileTim@@normalExposureTime:"5"
@@ProfileTim@@normalLayerDropHeight2:"0"
@@ProfileTim@@normalLayerDropSpeed:"210"
@@ProfileTim@@normalLayerDropSpeed2:"0"
@@ProfileTim@@normalLayerLiftHeight:"10"
@@ProfileTim@@normalLayerLiftHeight2:"0"
@@ProfileTim@@normalLayerLiftSpeed:"70"
@@ProfileTim@@normalLayerLiftSpeed2:"0"
@@ProfileTim@@normalLightIntensityPWM:"255"
@@ProfileTim@@normalRestTimeAfterLift:"0"
@@ProfileTim@@normalRestTimeAfterRetract:"0.5"
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

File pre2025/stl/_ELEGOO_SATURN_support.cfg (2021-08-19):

heavy_raftAngle:30
heavy_raftAreaRatio:110
heavy_raftHeight:1.8
heavy_raftShape:Skate
heavy_raftThickness:1.0
heavy_supportBottomDiameter:12
heavy_supportBottomShape:Skate
heavy_supportBottomThickness:1
heavy_supportMiddleDiameter:1.5
heavy_supportMiddleDiameter2:2.5
heavy_supportMiddleMaxConnectAngle:70
heavy_supportMiddleShape:Cylinder
heavy_supportMiddleSmallPillarDiameter:0.5
heavy_supportMiddleSmallPillarLowerContactDepth:0.3
heavy_supportMiddleSmallPillarShape:Cone
heavy_supportMiddleSmallPillarUpperContactDepth:0.3
heavy_supportTailTouchDepth:0.3
heavy_supportTipDownDiameter:1.5
heavy_supportTipLength:3.0
heavy_supportTipShape:Cone
heavy_supportTipTouchDepth:0.6
heavy_supportTipUpDiameter:0.6
heavy_supportTouchTailDiameter:2.0
heavy_supportTouchTailShape:None
heavy_supportTouchTipDiameter:1.0
heavy_supportTouchTipShape:None
light_raftAngle:30
light_raftAreaRatio:110
light_raftHeight:1.8
light_raftShape:None
light_raftThickness:1.0
light_supportBottomDiameter:10
light_supportBottomShape:Skate
light_supportBottomThickness:0.8
light_supportMiddleDiameter:0.8
light_supportMiddleDiameter2:1.0
light_supportMiddleMaxConnectAngle:70
light_supportMiddleShape:Cylinder
light_supportMiddleSmallPillarDiameter:0.4
light_supportMiddleSmallPillarLowerContactDepth:0.25
light_supportMiddleSmallPillarShape:Cone
light_supportMiddleSmallPillarUpperContactDepth:0.25
light_supportTailTouchDepth:0.2
light_supportTipDownDiameter:0.8
light_supportTipLength:2.0
light_supportTipShape:Cone
light_supportTipTouchDepth:0.02
light_supportTipUpDiameter:0.1
light_supportTouchTailDiameter:0.4
light_supportTouchTailShape:None
light_supportTouchTipDiameter:0.3
light_supportTouchTipShape:None
middle_raftAngle:30
middle_raftAreaRatio:110
middle_raftHeight:1.8
middle_raftShape:None
middle_raftThickness:1.0
middle_supportBottomDiameter:12
middle_supportBottomShape:Skate
middle_supportBottomThickness:1.0
middle_supportMiddleDiameter:1.2
middle_supportMiddleDiameter2:2.0
middle_supportMiddleMaxConnectAngle:70
middle_supportMiddleShape:Cylinder
middle_supportMiddleSmallPillarDiameter:0.5
middle_supportMiddleSmallPillarLowerContactDepth:0.02
middle_supportMiddleSmallPillarShape:Cone
middle_supportMiddleSmallPillarUpperContactDepth:0.3
middle_supportTailTouchDepth:0.2
middle_supportTipDownDiameter:1.2
middle_supportTipLength:2.0
middle_supportTipShape:Cone
middle_supportTipTouchDepth:0.4
middle_supportTipUpDiameter:0.4
middle_supportTouchTailDiameter:0.6
middle_supportTouchTailShape:None
middle_supportTouchTipDiameter:0.8
middle_supportTouchTipShape:None
supportWeight:light

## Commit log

2021-08-06 checkpoint
    initial population with dxf and stl files
    move things around
    start to construct parts spreadsheet
    more rearrangement, finished parts.ods
    [PalPro_BaseBack.dxf, PalPro_BaseBackBottom.dxf, PalPro_BaseBottom.dxf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]
2021-08-10 add cnc images, try table
    Update cnclist.md
    Another table test
    yet another test
    another try
    another
    again
    Update cnclist.md
    Update cnclist.md
    Update cnclist.md
    Update cnclist.md
    Update cnclist.md
    Update cnclist.md
    Create cnclist - Copy.md
    Update cnclist.md
    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
    [SPP_BaseBack.dxf, SPP_BaseBackBottom.dxf, SPP_BaseBottom.dxf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]
2021-08-10 more building description
    [SPP_MonLayer1_face.dxf]
2021-08-10 Add wood pieces to parts
    tweaks
    Update building.md
    [SPP_MonLayer1orig_face.dxf, parts.ods]
2021-08-17 parts tweak
    [inventory.ods, parts.ods]
2021-08-17 get rid of hdmi-usb C adapter
    [parts.ods]
2021-08-17 start including 3d printing files for brackets/mounts
    [amp_bracket.obj, amp_bracket.skp, amp_bracket.stl]
2021-08-17 bracket checkpoint
    [amp_bracket.skp, amp_bracket_half.skp, amp_bracket_half.stl]
2021-08-18 tweak bracket
    [amp_bracket_half.skp, amp_bracket_half.stl]
2021-08-18 tweak supports for bracket
2021-08-19 tweak building instructions
    [_ELEGOO_SATURN_support.cfg]
2021-08-19 more tweaks to bracket
    [amp_bracket_half.skp, amp_bracket_half.stl]
2021-08-20 tweak basebackbottom, add holes, shave the top
    [SPP_BaseBackBottom.dxf]
2021-08-21 make bottom part of bracket a tiny bit tighter
    [amp_bracket_half.skp, amp_bracket_half.stl]
2021-08-21 updated from stl
    [AI3MX_amp_bracket_half.3mf]
2021-08-22 tweaks to dxf
    [SPP_BaseBackShipping.dxf, SPP_BaseMidShelf.dxf]
2021-08-26 rearrange parts in parts.ods
    [parts.ods]
2021-08-27 improve building base instructions
    [SPP_BaseMidShelf.dxf, parts.ods]
2021-09-07 refine building instructions and images
    [amp_bracket_old.skp, amp_bracket_old.stl]
2021-12-18 increase hole size
    [SPP_BaseBackShipping.dxf]
2022-01-04 brackets for back lock and front panel
    [two_hole_bracket.skp, two_hole_bracket.stl, two_hole_front_bracket.skp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]
2022-01-04 add hole to side
    [SPP_BaseSide.dxf]
2022-01-06 make it smaller
    [two_hole_bracket.skp, two_hole_bracket.stl]
2022-01-06 3d print of brackets
2022-01-07 multiple brackets at once
2022-01-11 add holes to front, adjust side hole
    [SPP_BaseFront.dxf, SPP_BaseSide.dxf]
2022-01-15 lots of tweaks to CNC and STL
    [SPP_BaseFront.dxf, SPP_BaseSide.dxf, SPP_Layer7_back.dxf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]
2022-07-03 First cut at a more modular base box
    [SPP_basebox_bottom.dxf, SPP_basebox_frontback.dxf, SPP_basebox_side.dxf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]
2022-07-14 new version of modular baseboxes
    [SPP_baseboxes_large_back.dxf, SPP_baseboxes_large_side.dxf, SPP_baseboxes_small_back.dxf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]
2022-07-30 cnc data for new modular base
    [SPP_BaseBack.dxf, SPP_BaseBack_insert.dxf, SPP_BaseHeadphones_small.dxf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]
2022-08-15 Tweaks to new modular version
    [SPP_BaseBottom.dxf, SPP_BaseBottomLedge.dxf, SPP_Layer7_back.dxf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]
2022-08-22 adjust mounting holes
    [SPP_Layer7_back.dxf, SPP_baseboxes_small_side.dxf]
2023-02-09 dxf and stl
    [SPP_BaseBack_skp.dxf, two_hole_bracket_sketchup.stl]
2025-01-19 Tweaks for 2025 run of SPPs
    [SPP_Layer1_face.dxf, SPP_Layer2.dxf, SPP_Layer3.dxf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]
2025-05-30 checkpoint before starting fresh for modular base
    [basefront_noholes.dxf]
2025-05-30 first cut a modular rework
    [AI3MX_amp_bracket_half.3mf, SPP_BaseBack.dxf, SPP_BaseBackBottom.dxf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]
2025-08-01 put images and doc back
    Still needs a lot of work to document the new modular core piece.
    [SPP_Layer1_face.dxf, SPP_Layer2.dxf, SPP_Layer3.dxf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]
2026-05-22 Use current-tree gitleaks scan in Actions
